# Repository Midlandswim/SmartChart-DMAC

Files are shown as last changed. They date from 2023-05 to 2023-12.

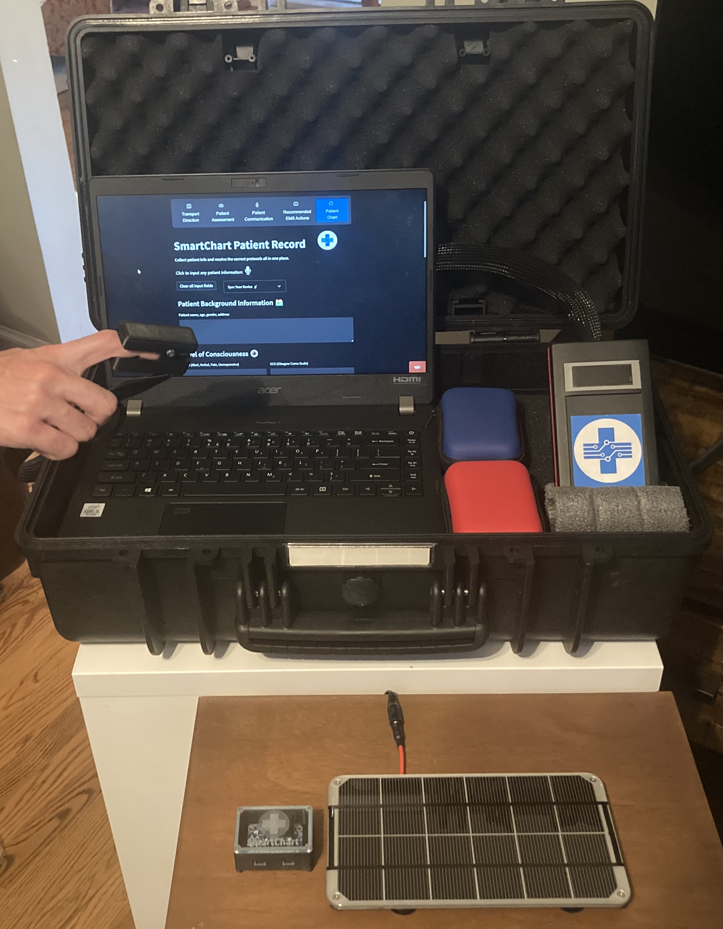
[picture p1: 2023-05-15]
Visuals/Photos/IMG_8333.jpg

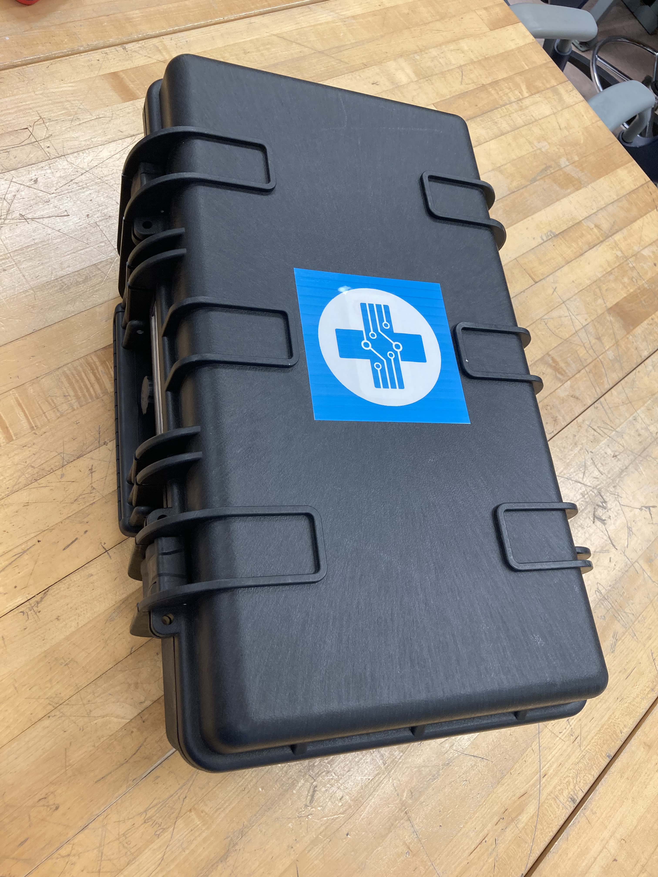
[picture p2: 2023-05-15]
Visuals/Photos/IMG_8315 (1).jpg

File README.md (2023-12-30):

# SmartChart & DMAC Research
SmartChart Patient Charting App and the Deployable Medical Assistance Case

Researcher: Wilson Dhalwani & Giacomo Pugliese <br />
Advisors: Mr. Michael Liva (BCA) & Mr. Joseph Barbetta (BCA) & Mr. Oliver Dobrich (BCA) & Ms. Clare Kennedy (BCA) <br />
Context: Future Health Professionals (HOSA) International Leadership Conference Medical Innovation <br />
Project Name: SmartChart & Deployable Medical Assistance Case <br />
Start Date: April 04, 2023 <br />

The following repository is for documenting and sharing my work in this research competition and its related fields of engineering and medicine. This was also made for recording my process of solving the issue at hand so that others can learn and build upon my work. An award-winning software that is the most intelligent and efficient virtual patient charting application for emergency medical technicians on the market, SmartChart utilizes an algorithm that suggests treatment based on patient information. A machine learning model provides diagnostics and appropriate protocols, and more. SmartChart supports audio transcription and translation for patient charting and communication, as well as OCR for written notes. The DMAC was made for our entry into the Medical Innovations Category at HOSA ILC. The team previously won 1st place at the HOSA New Jersey State Conference for Medical Innovation, allowing us to qualify for HOSA ILC in Dallas, TX, in 2023. I was not officially a member of the team during this time, only joining after their accomplishment at the New Jersey State Conference due to scheduling conflicts keeping me from joining the team in an official capacity prior to ILC Qualification. This is why I acted as an unofficial engineering consultant for the project up until the end of the New Jersey State Conference. We finished as semifinalists at HOSA ILC 2023, placing in the top 40 teams in the World. This was done in a team consisting of Giacomo Pugliese, Andrea Kim, and myself. I was the engineer in the group and personally designed the entire DMAC environment, including the aesthetics, custom enclosures, device programming, and solar power systems. The goal of this project is to work in concert with SmartChart, using AI to process and collect data to diagnose and treat patients. Used by EMTs, the DMAC and SmartChart will help revolutionize emergency patient care. This project is also patent pending, with the team recently being granted a provisional utility patent for the entire system. This project has no end date as an innovation never ends, rather, continues until the idea is forgotten, and my hope is that this work can be the basis for future engineers who, too, find great excitement in innovation and design. Featured by multiple news outlets. 
Here is the link to one by Yahoo Finance: https://finance.yahoo.com/video/students-design-smartchart-app-help-195534932.html?guccounter=1 <br />

<p align="center"> <strong> Promotional Video: </strong> </p> 

https://github.com/Midlandswim/SmartChart-DMAC/assets/87616332/fc35b12c-a720-4e8d-b312-f2718276814c

<br />

Should you have any questions, comments, or just wish to reach out, email me at wilson.dhalwani@gmail.com !

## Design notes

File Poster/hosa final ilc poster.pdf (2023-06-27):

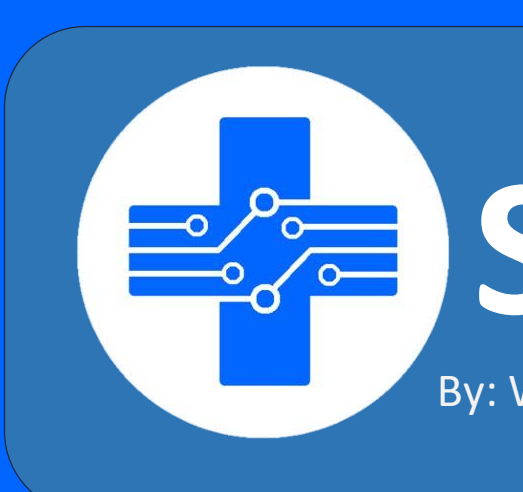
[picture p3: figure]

### By: Wilson Dhalwani, Andrea Kim, & Giacomo Pugliese

### MISSION STATEMENT

EMT workers are often put under high pressure, where providing the right diagnosis and treatment can mean life or death for the patient. Our mission is to create an app and hard case with integrated artificial intelligence and computer vision for EMTs, that enhances their ability to provide timely and effective care to patients. With this, we seek to minimize the time EMTs spend on documentation or looking up protocols, allowing them to maximize their time spent on patient care and call planning. We believe that our app has the potential to revolutionize the way EMTs deliver emergency medical care, enabling them to make more informed decisions and provide faster, more effective treatment to patients.

### OUR INNOVATION

We created an artificial intelligence integrated web application, SmartChart, designed for the efficient and consistent delivery of EMS care. An interface was created for EMTs to record vitals and patient care summaries while continuously updating the patient care suggestions tab, a separate page that includes a patient care overview recommended by the algorithm. In addition, a machine learning model was created to take in images and return possible patient complications. Other features included are on-demand translations for language barriers and transport directions to recommended medical facilities. This app is paired with our DMAC, or Deployable Medical Assistance Case. This is an entire environment for recording and storing data, taken by inbuilt sensors or human interface. It is capable of taking real time vitals and sending them to SmartChart, for AI related processing.

### Recommended EMS Actions

- Lists recommended actions that live updates dynamically to each patient, according to the algorithm.
- Each result also indicates possible contraindications and relative contraindications based on the patient’s information.

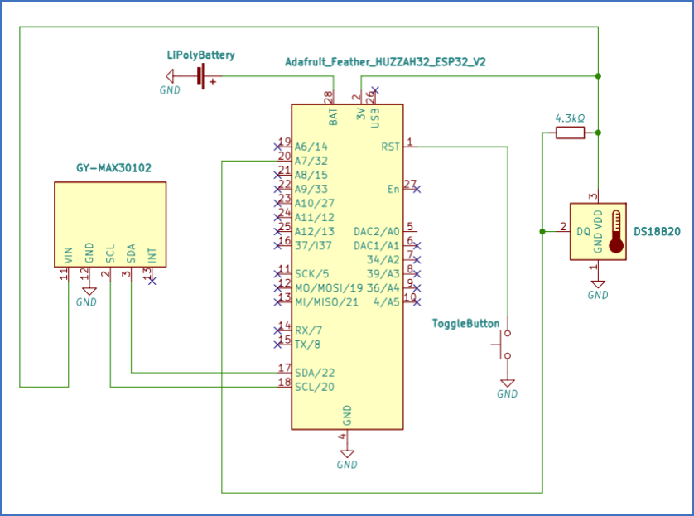
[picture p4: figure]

### Transport Directions

- Alerts EMT about inclement weather conditions.
- Provides a list of the nearest facilities including hospitals, burn centers, trauma centers, stroke centers, and cardiac centers.
- Recommends and reorders nearby facility types and provides directions based on patient information.

### Patient Communication

- On-demand translations help with language barriers
- Conversations can be audio or text-based
- 10 language options to translate the EMT or the patient’s message

### HOW IT WORKS

In the web app, users can navigate through the different tabs by using a convenient navigation bar.

### Patient Chart

- EMTs can enter vitals manually or use the voice input to save time. There is also an area for inputting the EMTs hand written care report into the chart using optical character recognition
- AI was designed for the voice input understand recognize all speech patterns, understand them in any order, and take as many vitals as needed.
- Patient charts can be saved and exported.

### PRACTITIONERS & TRAINING REQUIREMENTS

This app and case are created for EMTs to use on-duty. Users must be certified EMTs in order to ensure that they have the background knowledge and training necessary, to correctly carry-out actions. The case and website are easy to use and maintain.

### COST ANALYSIS

Combined, the total material cost of SmartChart per case comes to be less than $150 (excluding the computer). The web app has no costs other than maintenance activities and hosting. Our goal is to provide quality healthcare to all people, so we want to minimize the price as much as possible. To do this, SmartChart could apply for an SBIR grant (small business innovation research). Funding would be used to find ways to minimize costs of production and further develop the product.

### IMPACT ON FUTURE HEALTHCARE

Our goal is to empower EMTs with the tools and knowledge they need to save lives, reduce patient morbidity and mortality, and improve the overall quality of emergency medical care. We hope that by using our app, patients can receive faster and more accurate diagnoses as well as receive the quality treatment they need.

# SmartChart

The algorithm for determining all possible patient conditions according to their information chart:

**Disclaimer: All above images are original student images**

3D render of custom CAD finger pulse oximeter clip:

The electronic schematic for the deployable medical assistance case enclosure:

3D render of custom CAD solar charger enclosure:

### THE DEPLOYABLE MEDICAL ASSISTANCE CASE (DMAC)

The DMAC houses a microcontroller, a pulse oximeter, a temperature probe, and a secure and portable electronics enclosure for the battery. The enclosure includes a customizable LiPo battery system and onboard Wi-Fi interfacing. The DMAC also comes with a solar panel system capable of fully charging the case in just about 60 minutes. The data is then sent, recorded, and processed in real-time, allowing for accurate and efficient care of the patient.

### Adafruit ESP32 Feather HUZZAH V2

A compact and powerful microcontroller board based on the ESP32 chipset. It offers built-in Wi-Fi and Bluetooth capabilities, making it ideal for projects requiring wireless connectivity. With its small form factor and rich features, it enables easy prototyping and development of IoT applications.

### Adafruit MCP73871 Solar Charger

A handy device designed to charge Lithium Polymer (LiPo) batteries using solar power. It incorporates a specialized charging chip that efficiently regulates charging, ensuring optimal battery performance and longevity. It is an excellent choice for projects that require sustainable and eco-friendly power sources.

### GY-MAX30102 Pulse Ox and Heart Rate Sensor

A highly sensitive and accurate sensor module that measures both heart rate and blood oxygen saturation levels. It utilizes infrared and red-light sensors to detect changes in blood volume, providing valuable data for monitoring health and wellness.

### DS18B20 Temperature Sensor

A digital thermometer that measures temperature with high precision. It uses a unique one-wire protocol, allowing multiple sensors to be connected to a single microcontroller pin. It has a compact size and waterproof casing.

### Adafruit LiPo Battery 3.7V 500mAh

A rechargeable Lithium Polymer (LiPo) battery specifically designed for small electronic projects. It offers a high energy density and a compact form factor, making it suitable for applications where space is limited.

Source: Adafruit Industries

Source: Adafruit Learning Systems

Source: Amazon

Source: Adafruit Industries

### Patient Assessment

- Trained a machine learning model to classify different patient presentations using computer vision technology.
- Presents relevant protocols based on classification to save time for the EMT

Source: Amazon

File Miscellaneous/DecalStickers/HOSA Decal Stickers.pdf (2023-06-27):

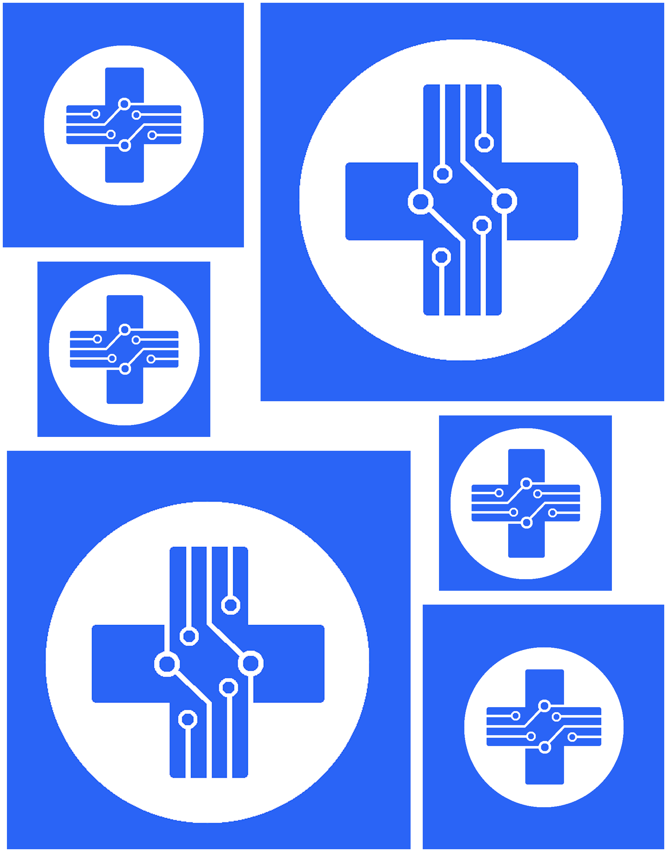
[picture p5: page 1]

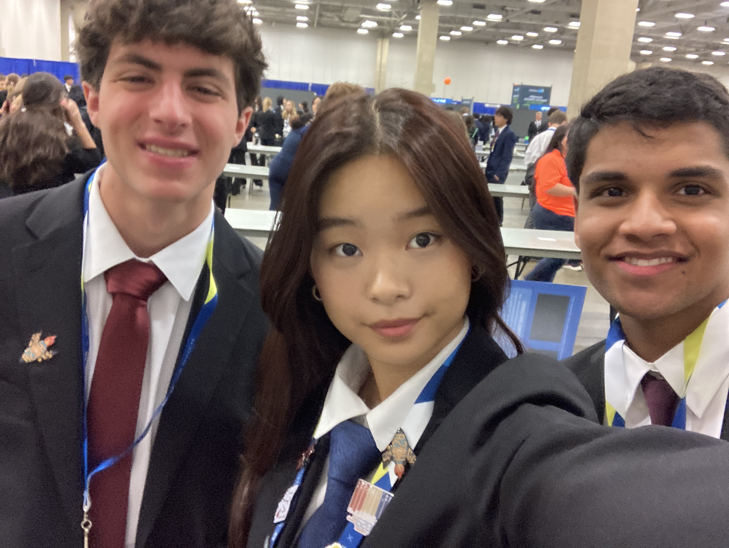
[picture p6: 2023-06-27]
Visuals/Photos/HOSAGroupPhotoPic.jpg

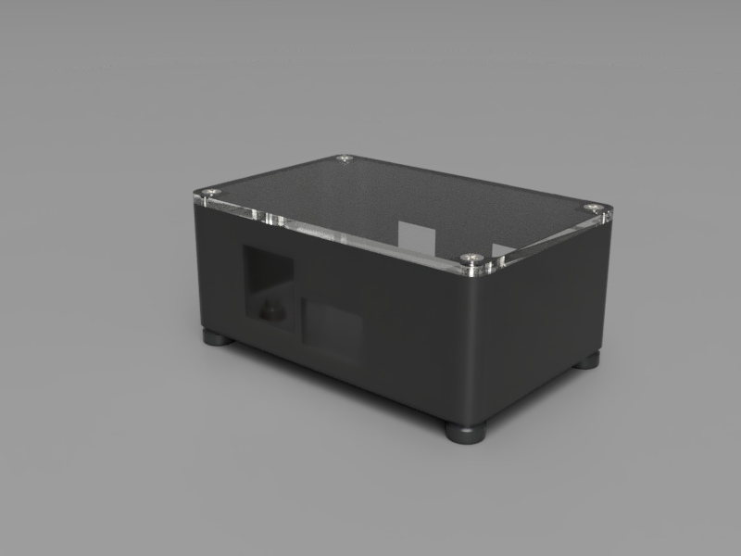
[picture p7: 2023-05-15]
Visuals/Renders/MCP73871Enclosure_2023-May-13_01-03-16AM-000_CustomizedView6770993901_png.png

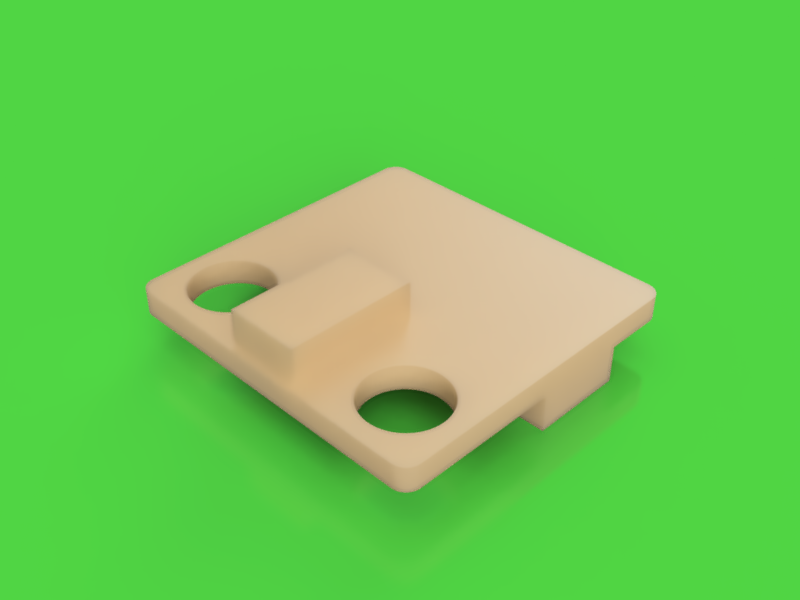
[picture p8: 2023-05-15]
Visuals/Renders/GY-MAX30102PCBRender1.png

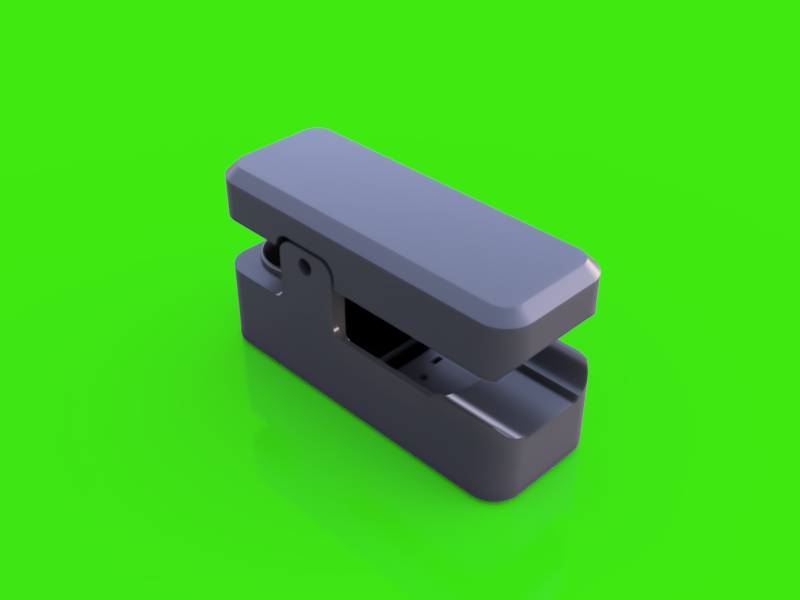
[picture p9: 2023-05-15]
Visuals/Renders/PulseOxiRender6.png

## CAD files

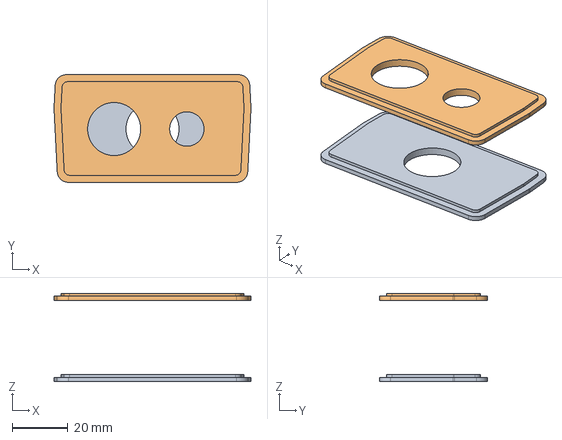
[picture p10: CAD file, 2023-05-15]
CAD/Components/Enclosure Walls/HOSAEnclosureWalls STEP.step
70.4 x 38.5 x 31.5 mm

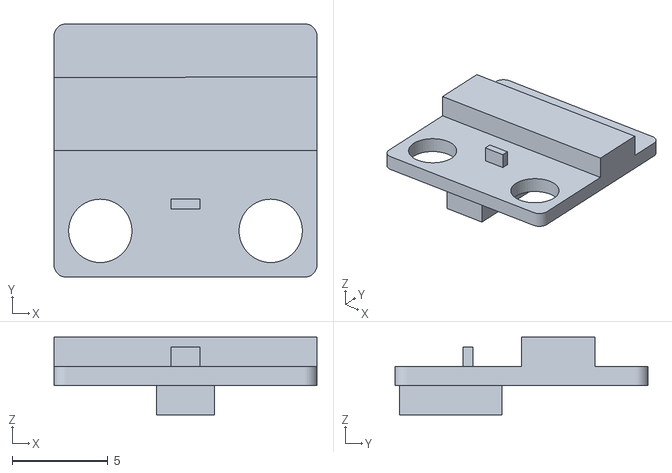
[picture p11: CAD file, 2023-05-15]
CAD/Components/GY-MAX30102/GY-MAX30102 Component STL.stl
13.7 x 13.2 x 4.06

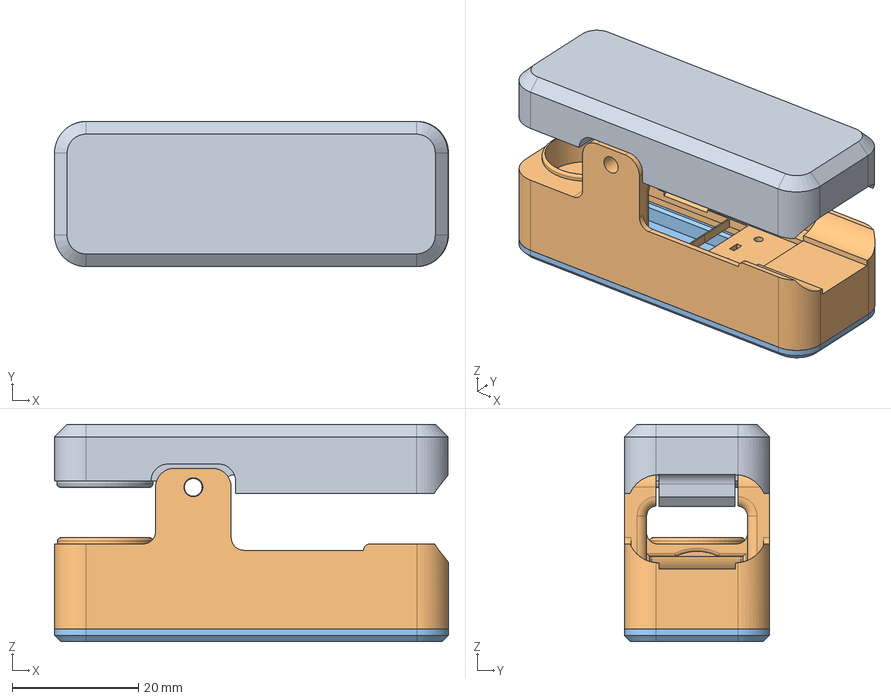
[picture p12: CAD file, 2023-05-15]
CAD/Pulse Oximeter Clip/PulseOximeterClip STEP.step
62.5 x 23.0 x 34.5 mm
Top
Bottom

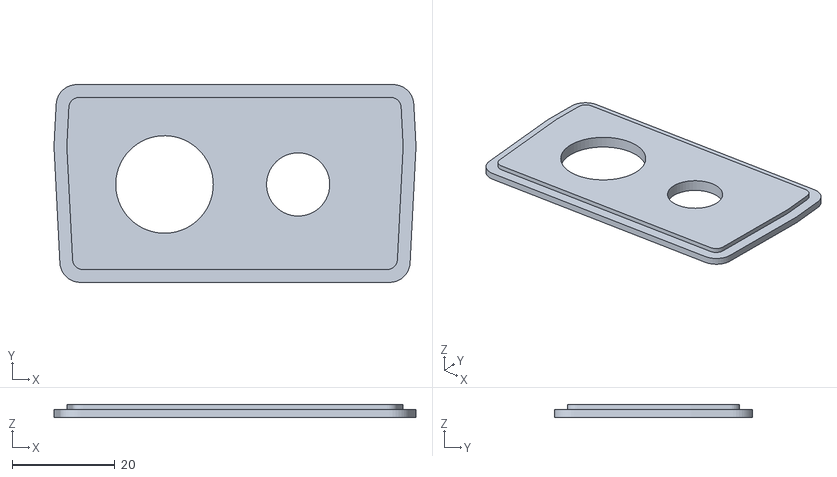
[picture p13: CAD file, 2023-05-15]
CAD/Components/Enclosure Walls/HOSAEnclosureWalls DoubleHole STL.stl
70.4 x 38.5 x 2.50

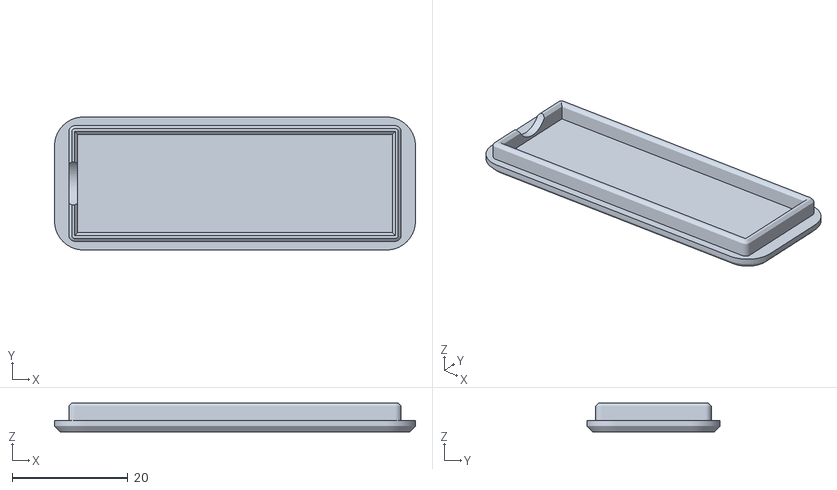
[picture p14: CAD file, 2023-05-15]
CAD/Pulse Oximeter Clip/PulseOximeterClip Bottom STL.stl
62.4 x 23.0 x 5.00

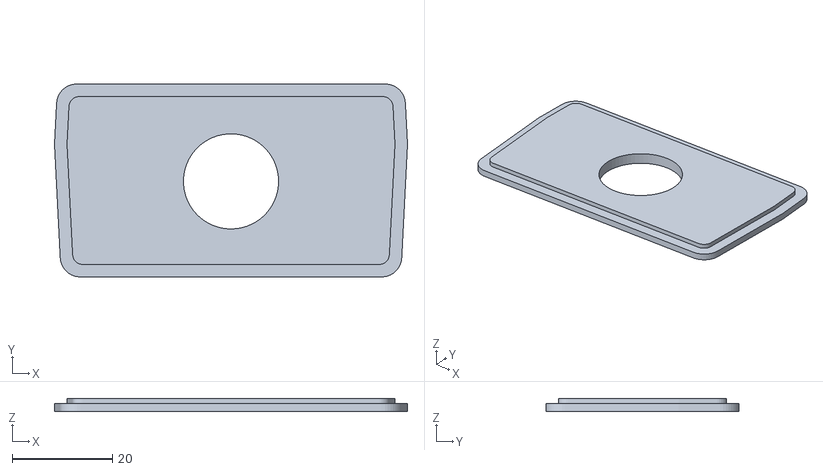
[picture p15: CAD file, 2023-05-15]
CAD/Components/Enclosure Walls/HOSAEnclosureWalls SingleHole STL.stl
70.4 x 38.5 x 2.50

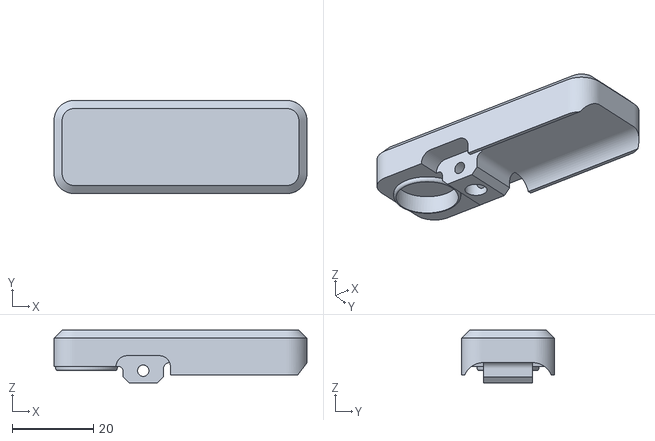
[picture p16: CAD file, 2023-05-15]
CAD/Pulse Oximeter Clip/PulseOximeterClipTop STL.stl
62.4 x 23.0 x 13.0

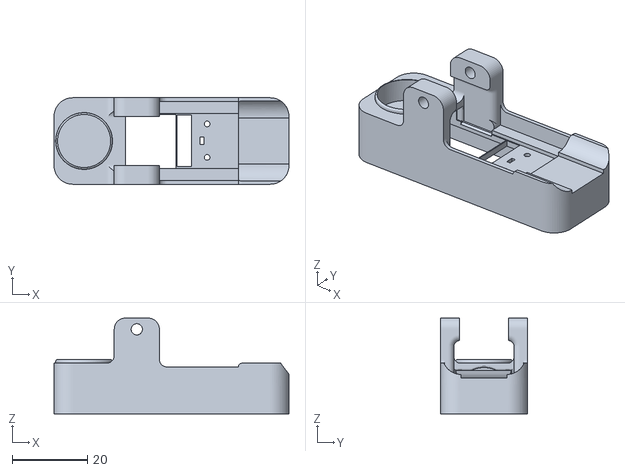
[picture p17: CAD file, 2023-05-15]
CAD/Pulse Oximeter Clip/PulseOximeterClipMiddle STL.stl
62.4 x 23.0 x 25.5

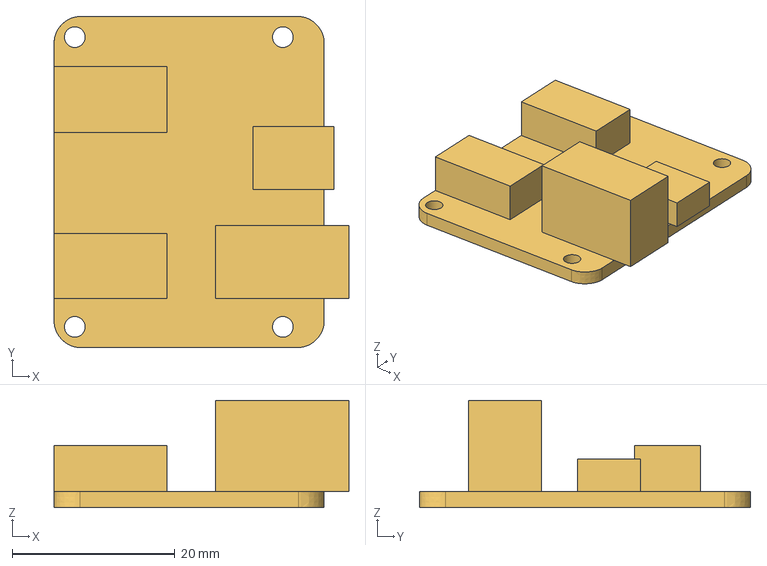
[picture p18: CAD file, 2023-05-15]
CAD/Components/MCP73871/MCP73871 Solar Charger Controller STEP.step
36.2 x 40.7 x 13.2 mm

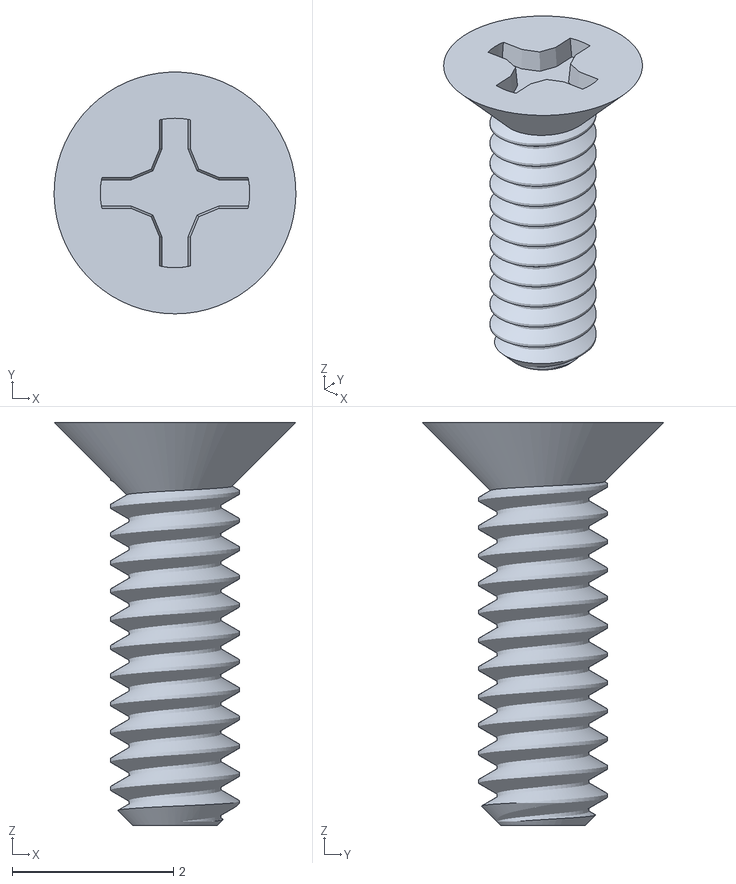
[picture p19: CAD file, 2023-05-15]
CAD/Components/Screws/92010A781_Passivated 18-8 Stainless Steel Phillips Flat Head Screw STL.stl
3.00 x 3.00 x 5.00

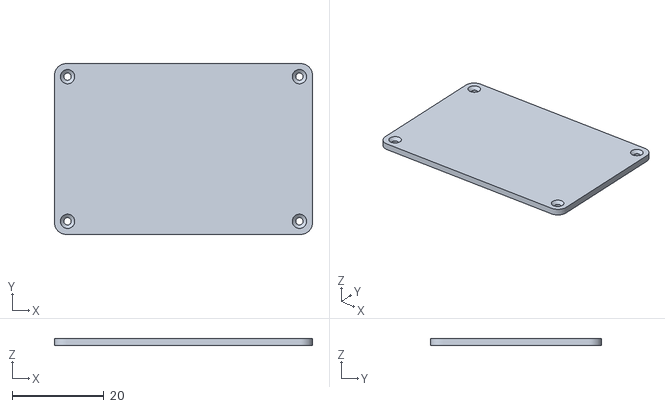
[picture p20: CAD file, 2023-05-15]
CAD/Solar Charger Enclosure/MCP73871Enclosure Accrylic Cover STL.stl
56.3 x 37.2 x 1.59

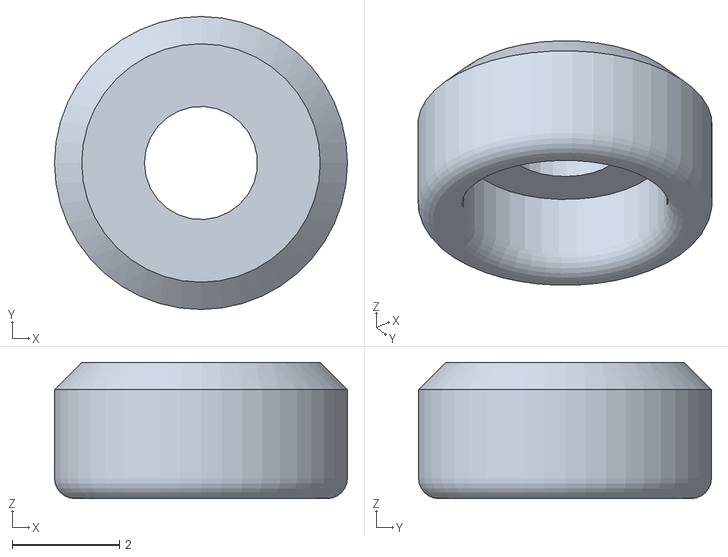
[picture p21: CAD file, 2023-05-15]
CAD/Solar Charger Enclosure/MCP73871Enclosure Leg STL.stl
5.46 x 5.46 x 2.54

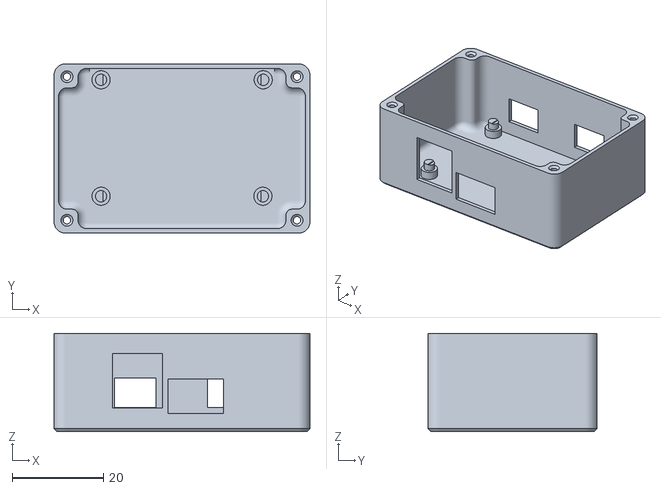
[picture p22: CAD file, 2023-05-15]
CAD/Solar Charger Enclosure/MCP73871Enclosure Body STL.stl
56.3 x 37.2 x 21.6

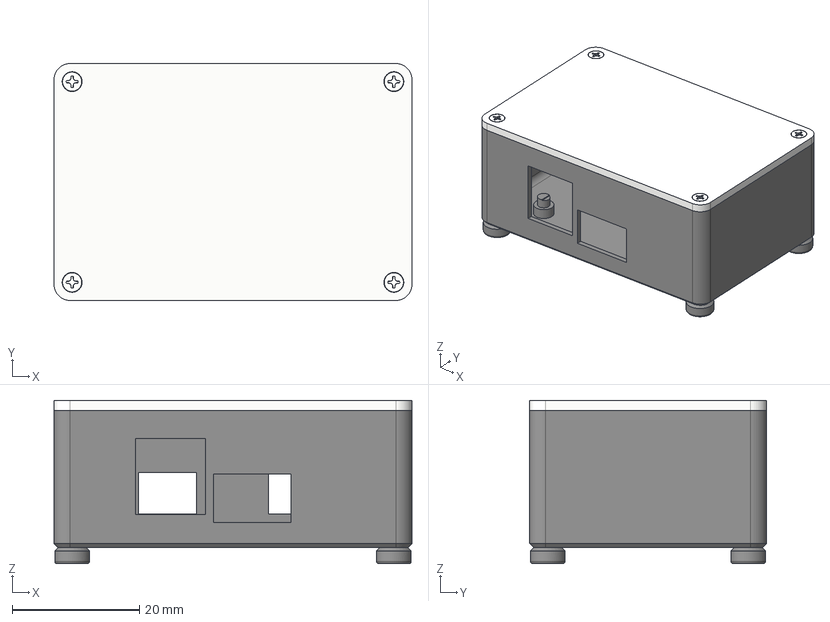
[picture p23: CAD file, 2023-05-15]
CAD/Solar Charger Enclosure/MCP73871Enclosure STEP.step
56.3 x 37.2 x 25.7 mm
92010A781_Passivated 18-8 Stainless Steel Phillips Flat Head Screw v2 x 8

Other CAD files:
CAD/Components/GY-MAX30102/GY-MAX30102 Component STEP.step
CAD/Components/Enclosure Walls/HOSAEnclosureWalls .step
CAD/Components/MCP73871/MCP73871 Solar Charger Controller STL.stl
CAD/Components/Screws/92010A781_Passivated 18-8 Stainless Steel Phillips Flat Head Screw STEP.step
CAD/Components/GY-MAX30102/GY-MAX30102 Component CAD.f3d
CAD/Components/MCP73871/MCP73871 Solar Charger Controller.f3d
CAD/Components/Screws/92010A781_Passivated 18-8 Stainless Steel Phillips Flat Head Screw .f3d
CAD/Pulse Oximeter Clip/PulseOximeterClip.f3z
CAD/Solar Charger Enclosure/MCP73871Enclosure .f3z

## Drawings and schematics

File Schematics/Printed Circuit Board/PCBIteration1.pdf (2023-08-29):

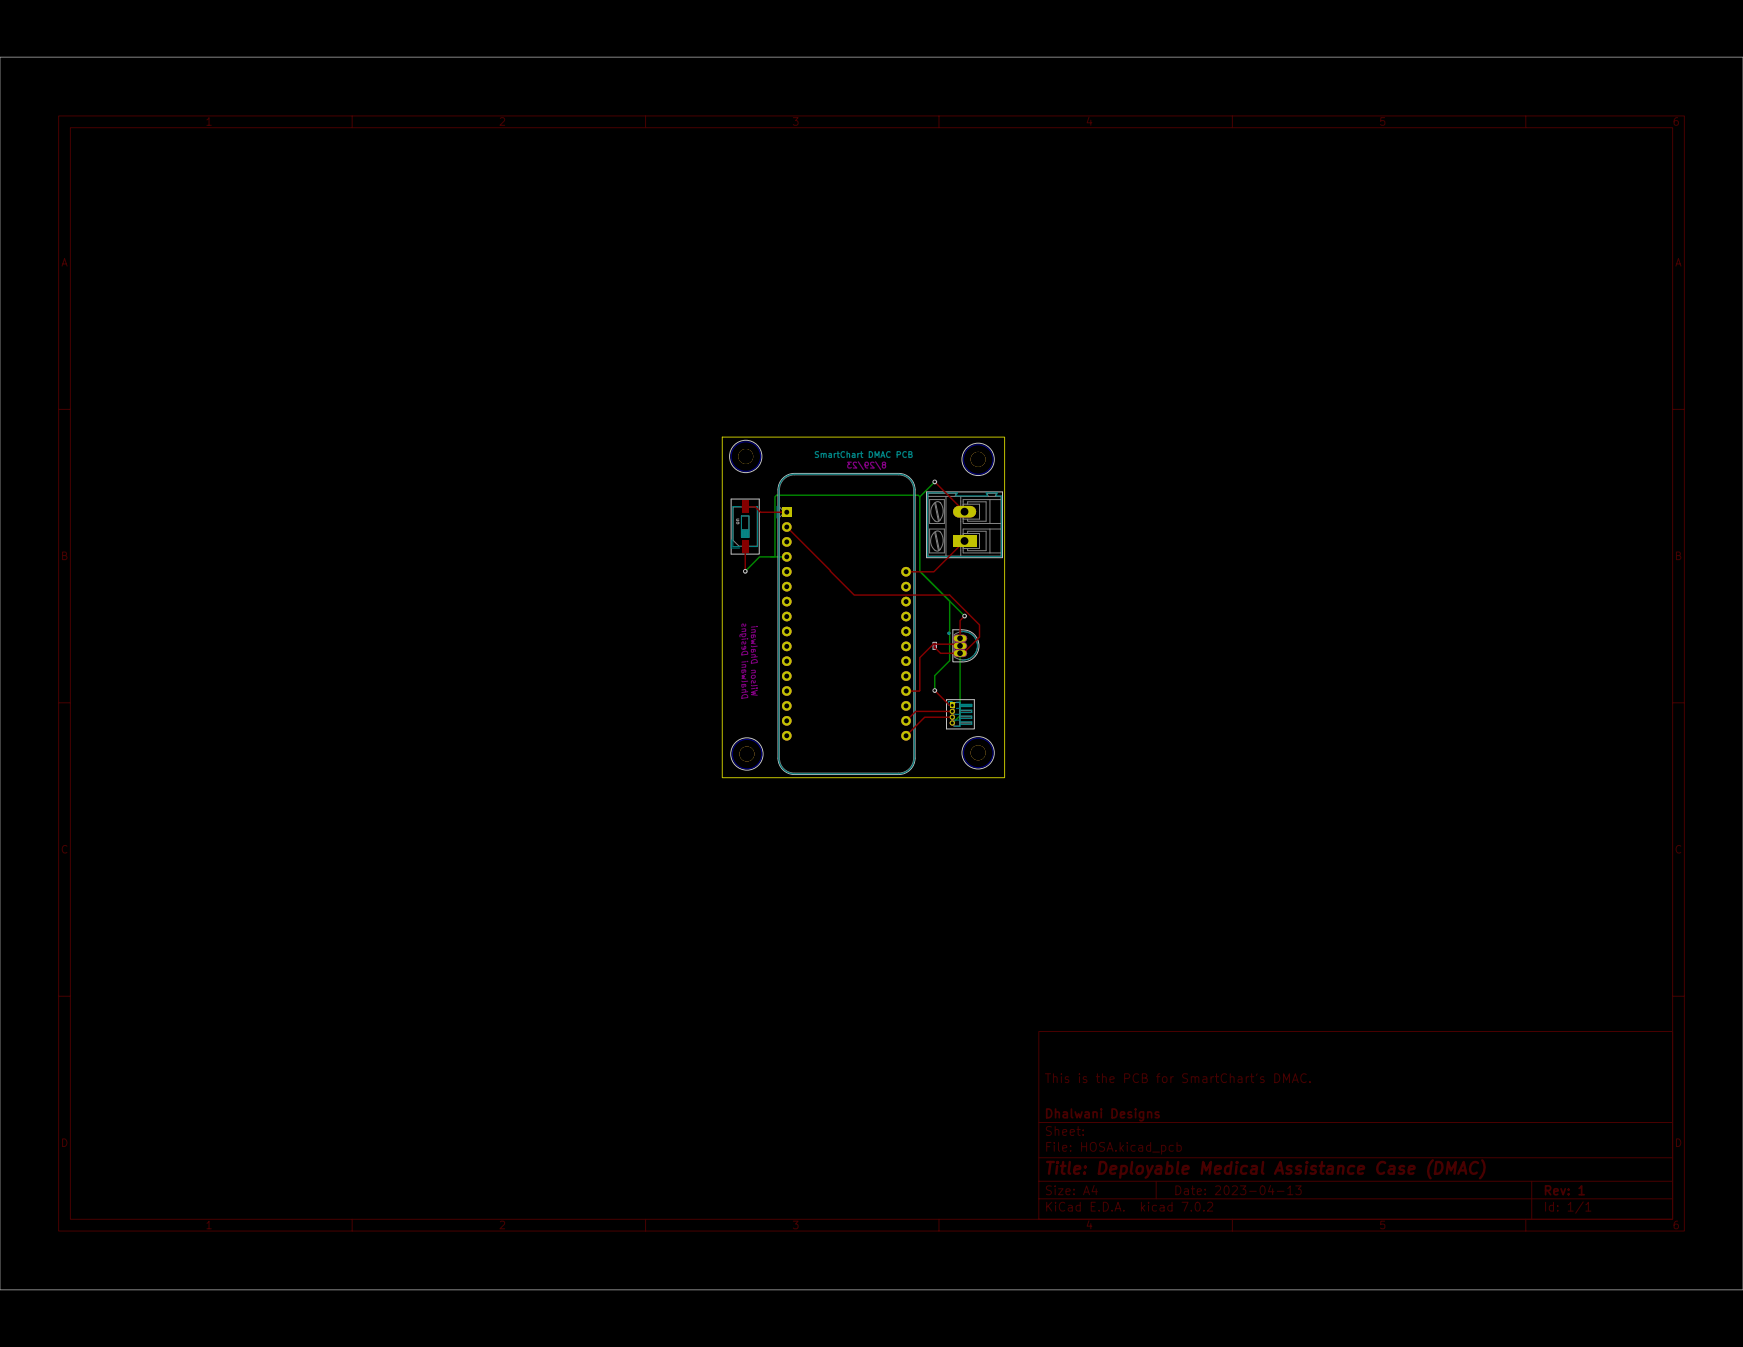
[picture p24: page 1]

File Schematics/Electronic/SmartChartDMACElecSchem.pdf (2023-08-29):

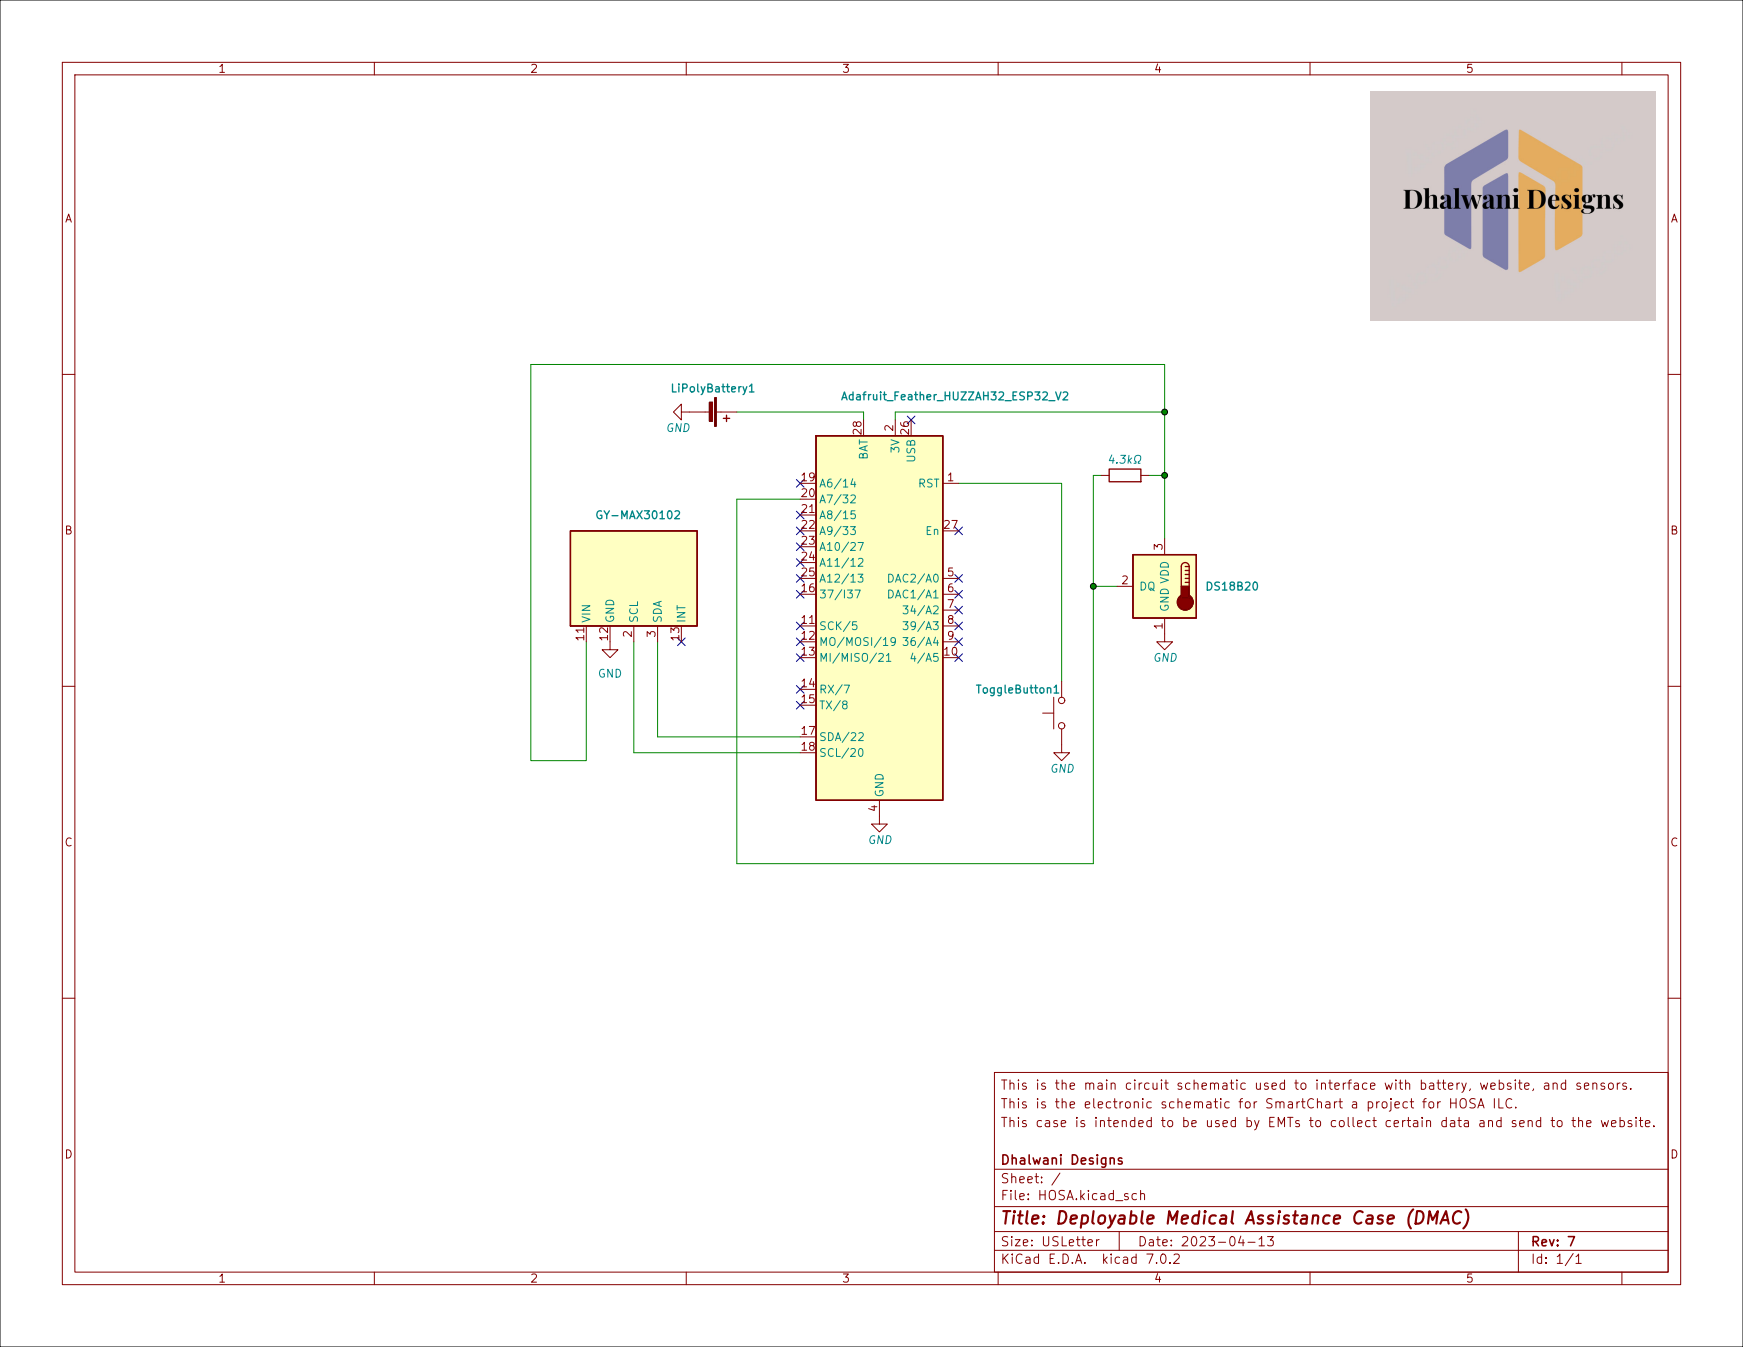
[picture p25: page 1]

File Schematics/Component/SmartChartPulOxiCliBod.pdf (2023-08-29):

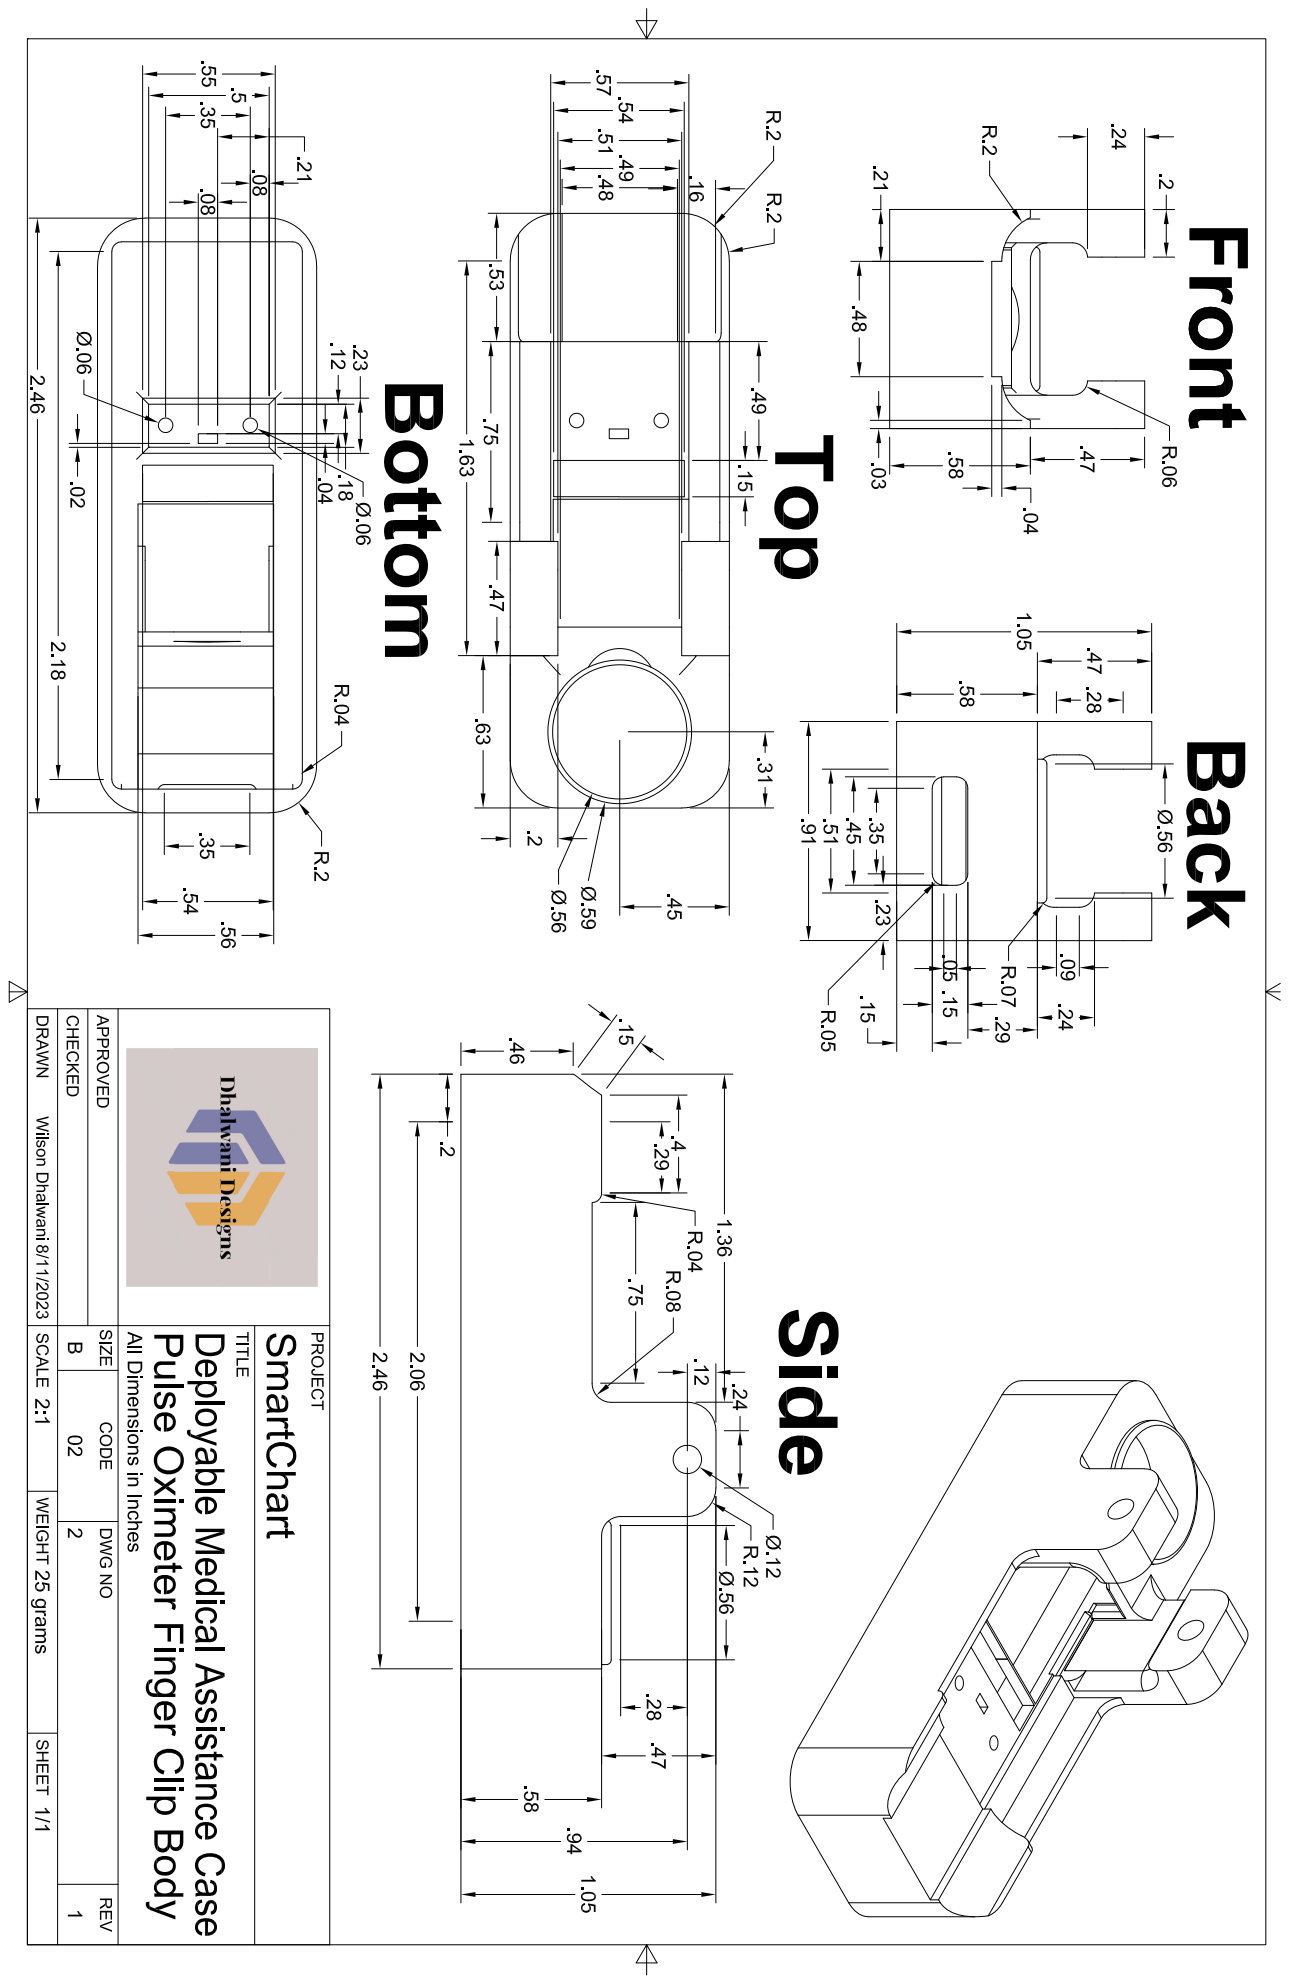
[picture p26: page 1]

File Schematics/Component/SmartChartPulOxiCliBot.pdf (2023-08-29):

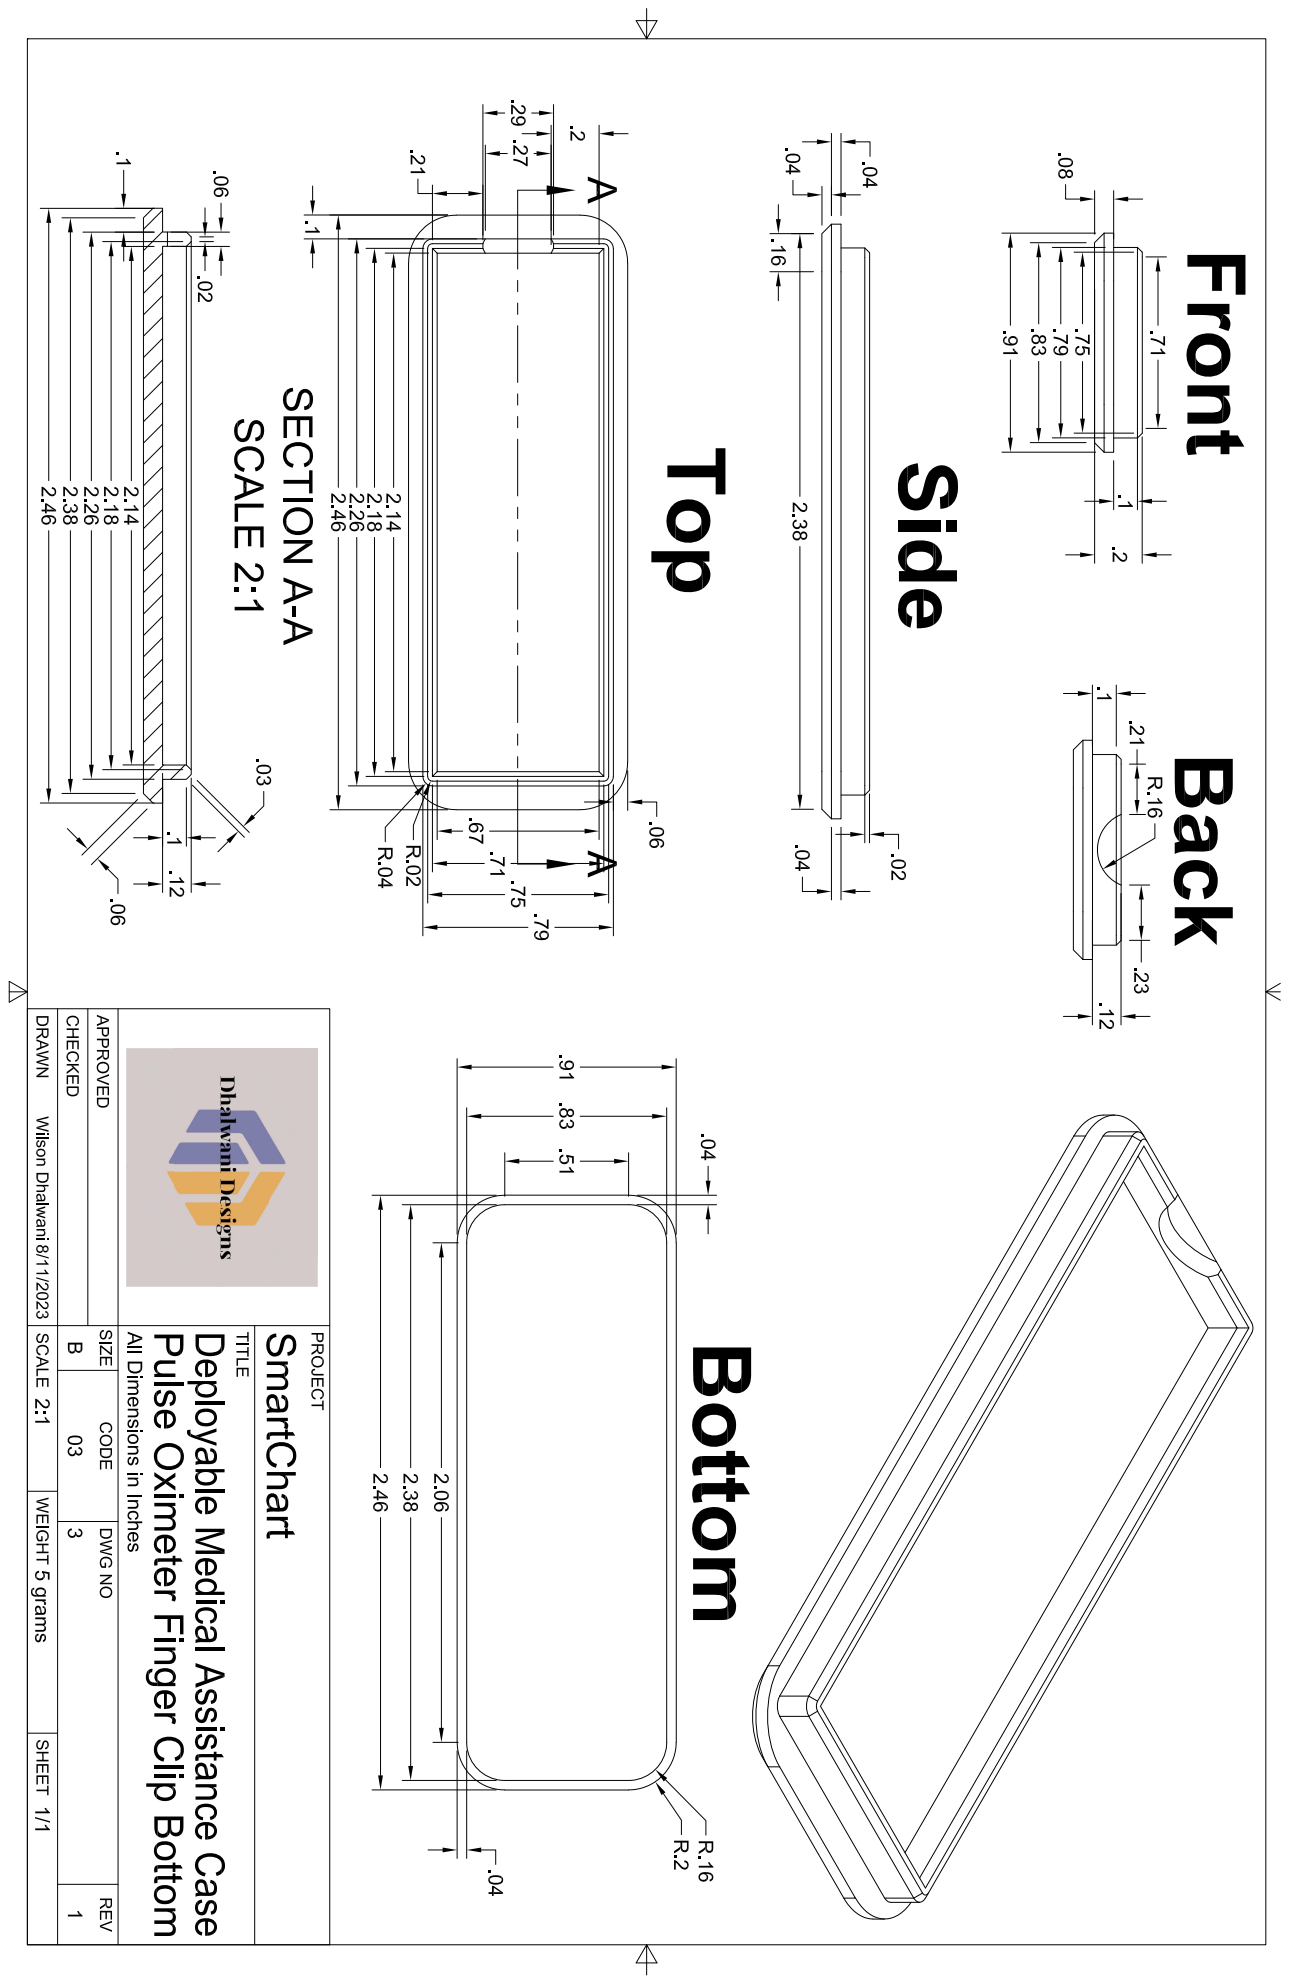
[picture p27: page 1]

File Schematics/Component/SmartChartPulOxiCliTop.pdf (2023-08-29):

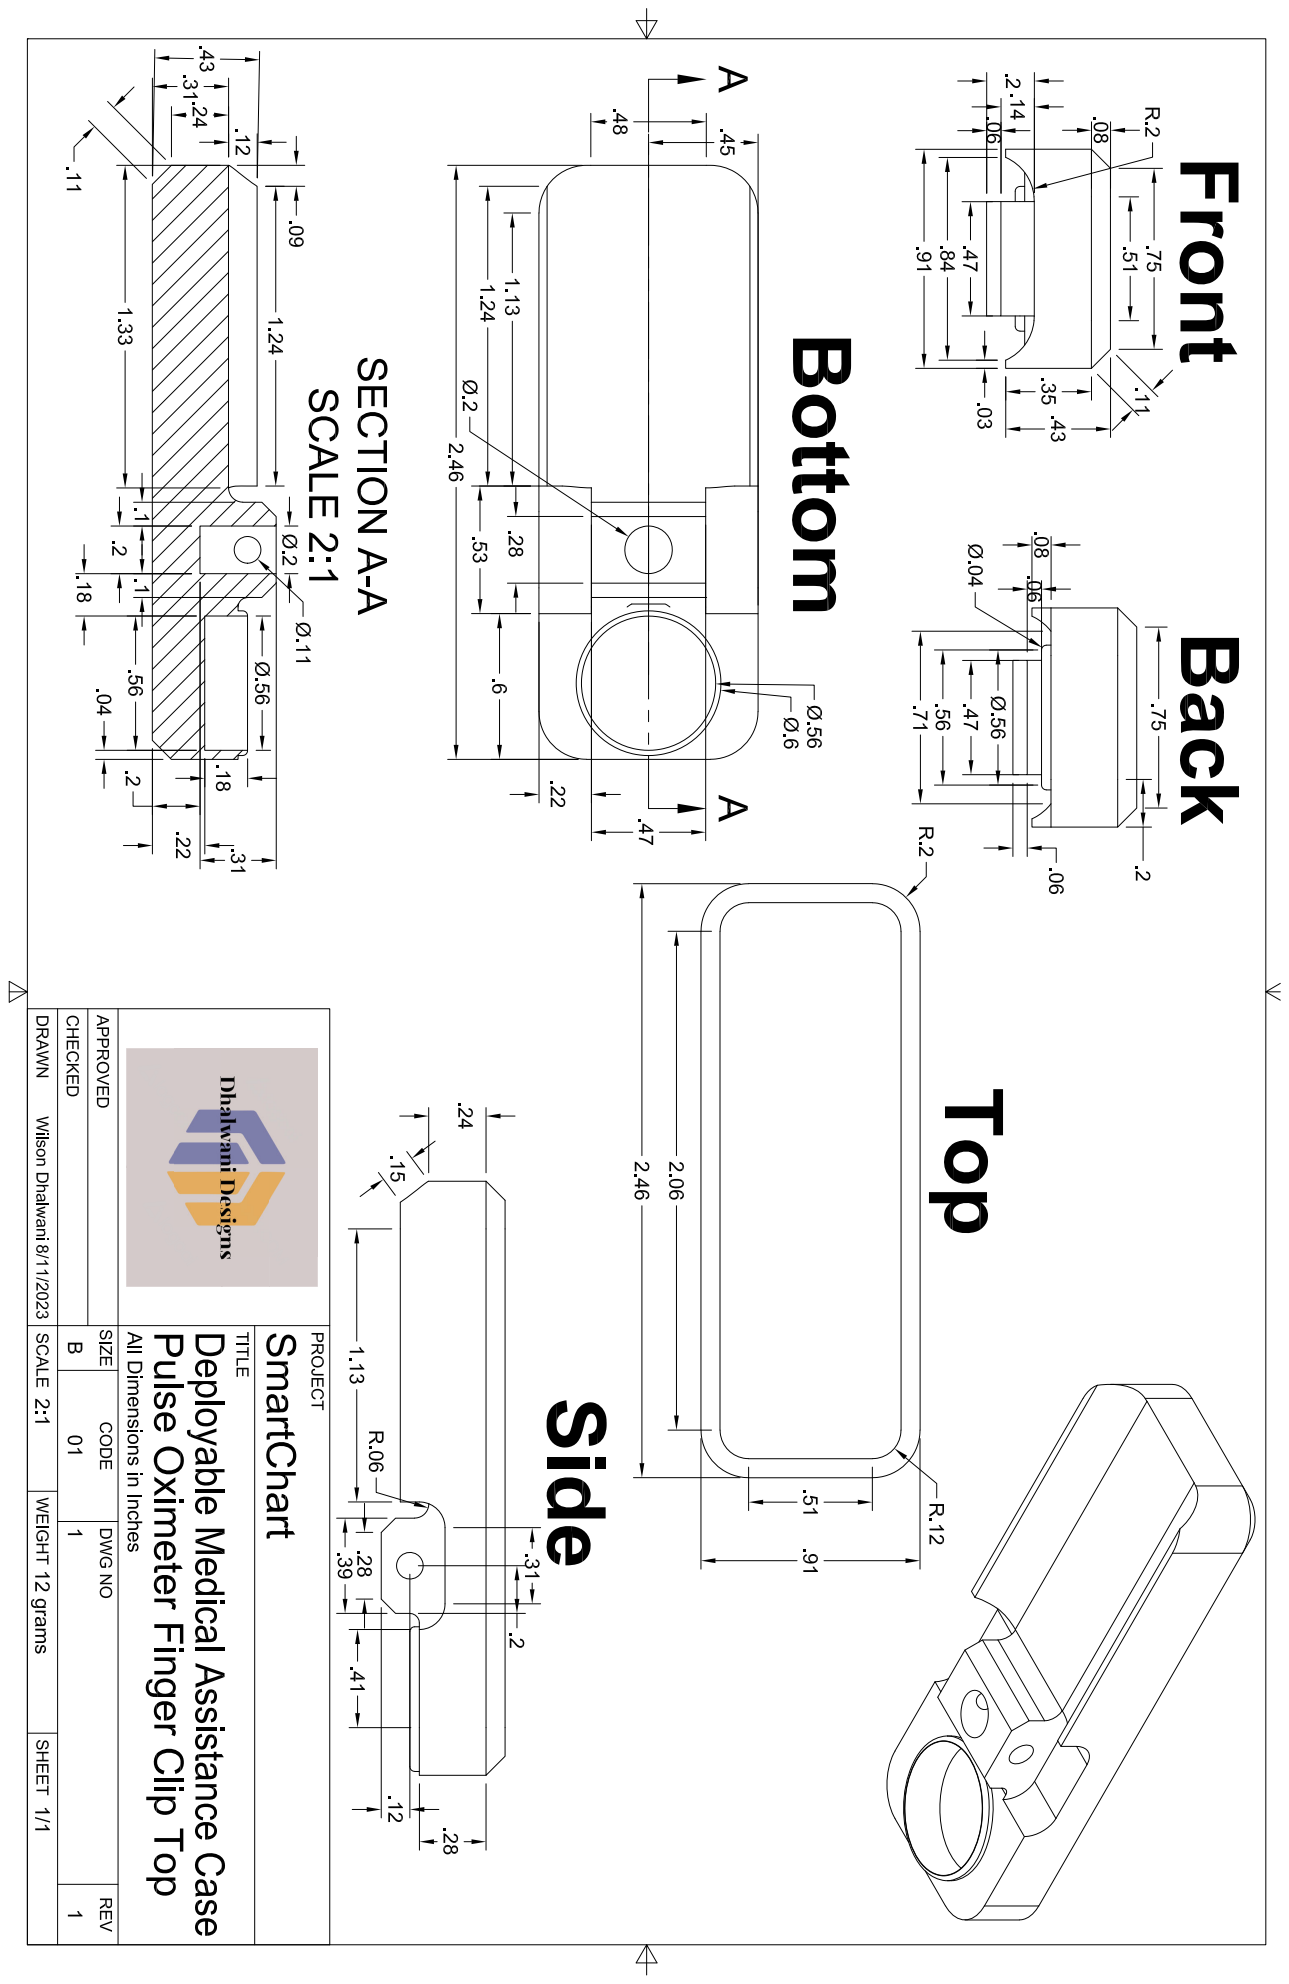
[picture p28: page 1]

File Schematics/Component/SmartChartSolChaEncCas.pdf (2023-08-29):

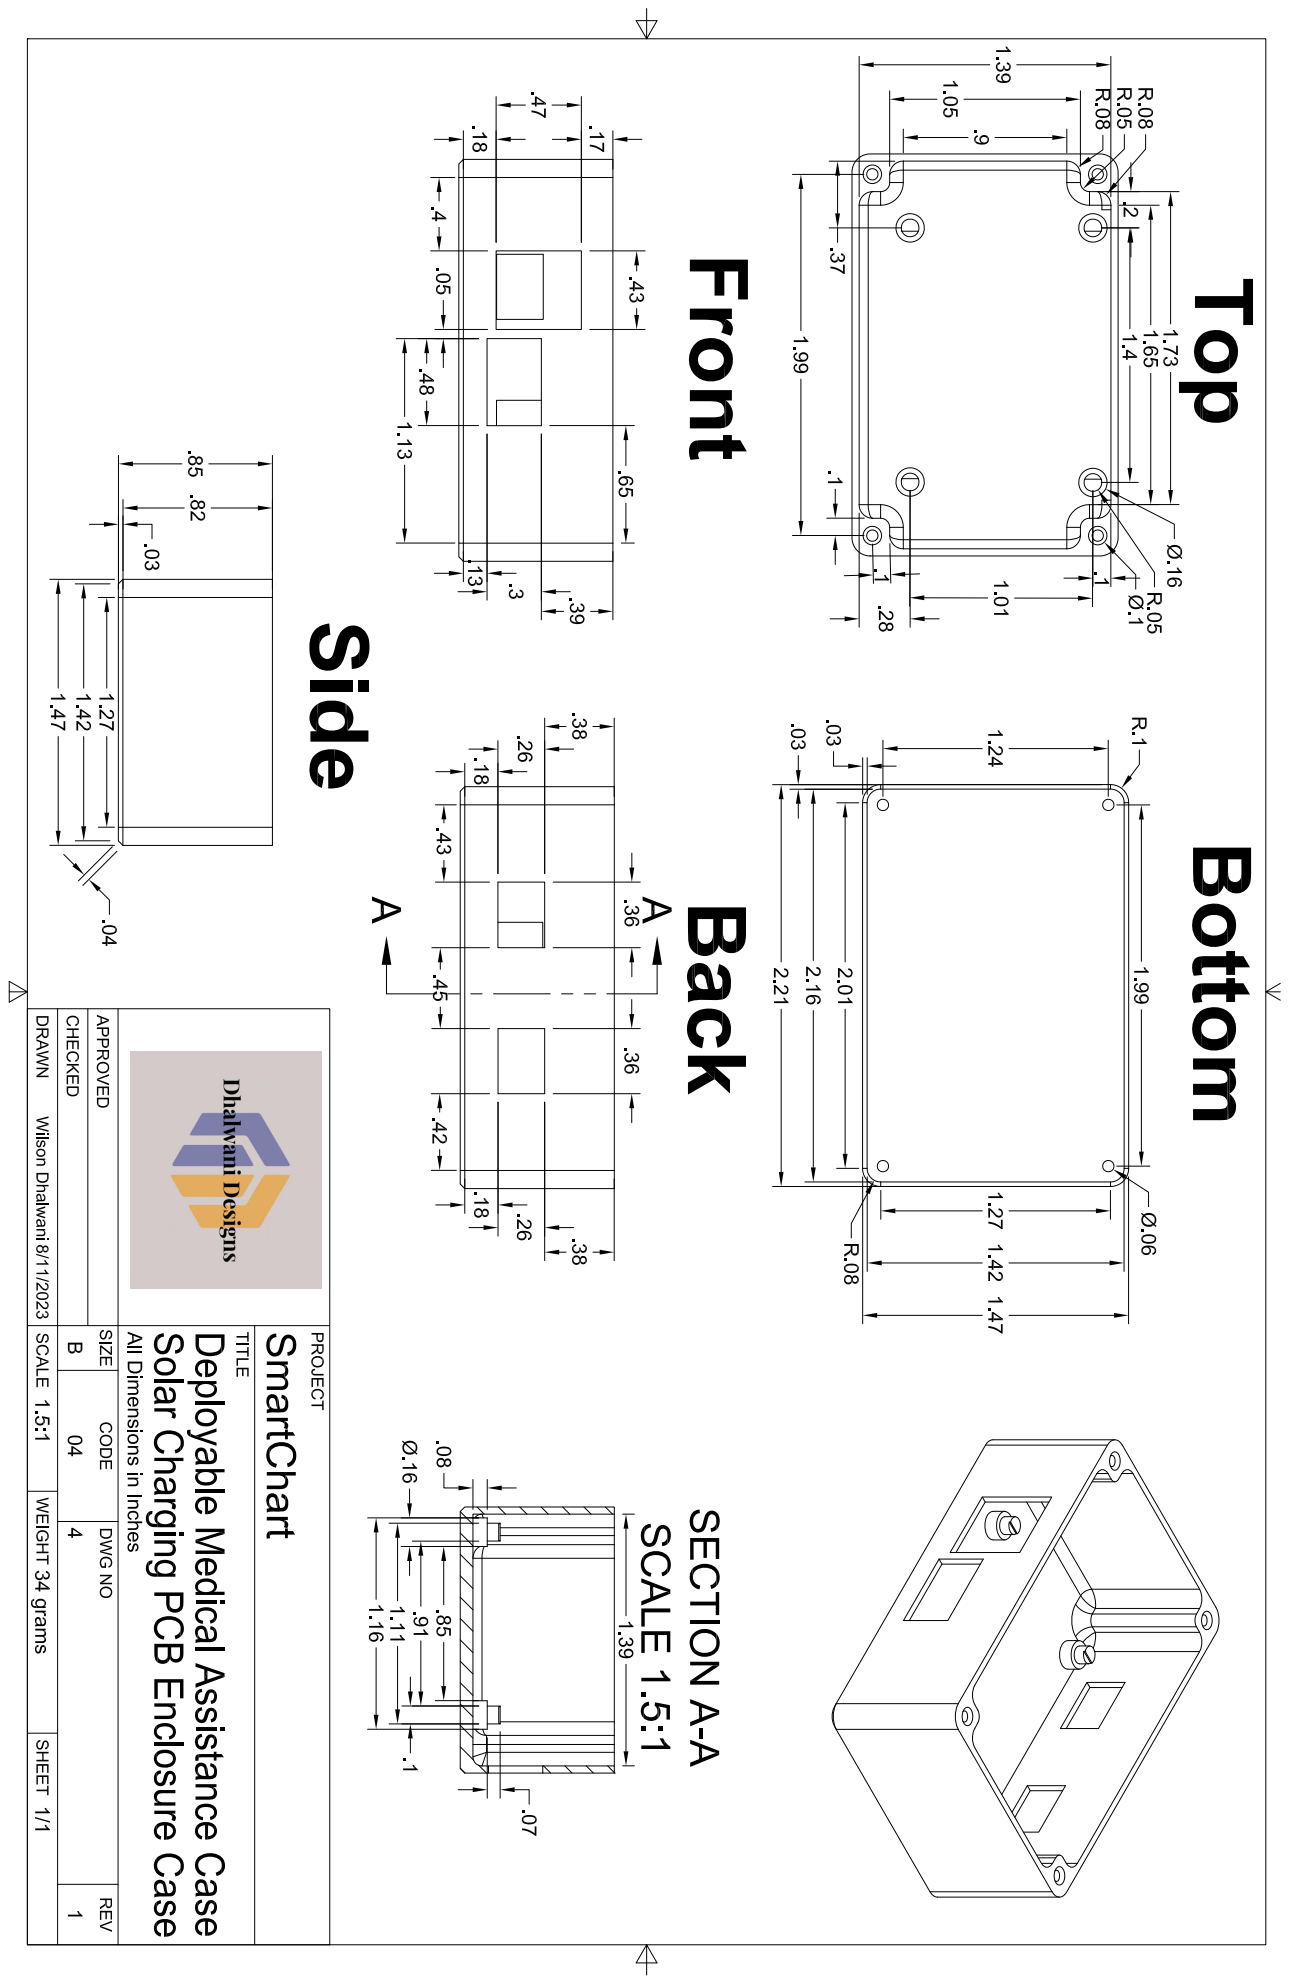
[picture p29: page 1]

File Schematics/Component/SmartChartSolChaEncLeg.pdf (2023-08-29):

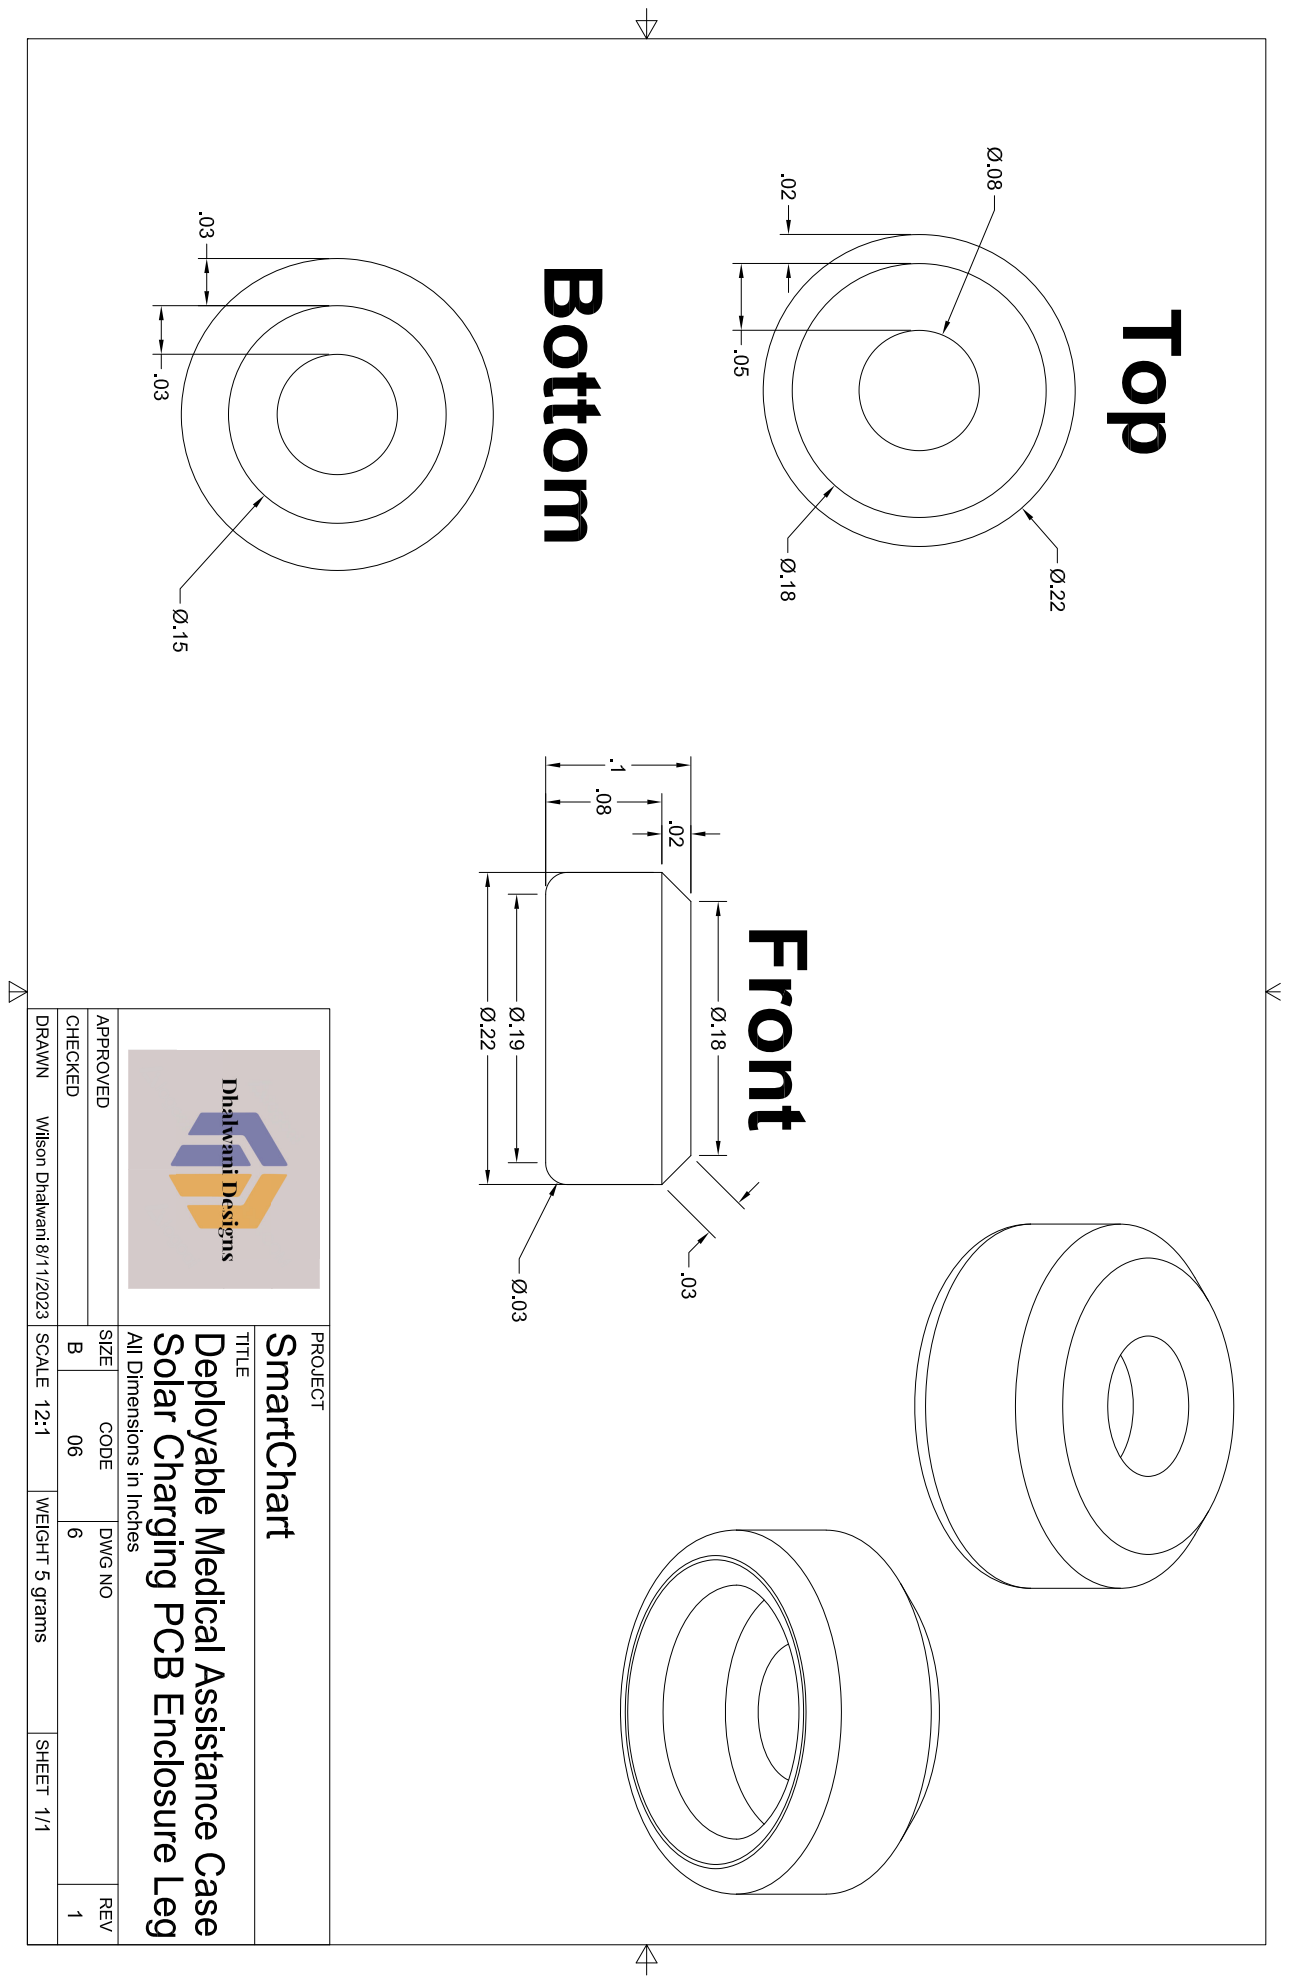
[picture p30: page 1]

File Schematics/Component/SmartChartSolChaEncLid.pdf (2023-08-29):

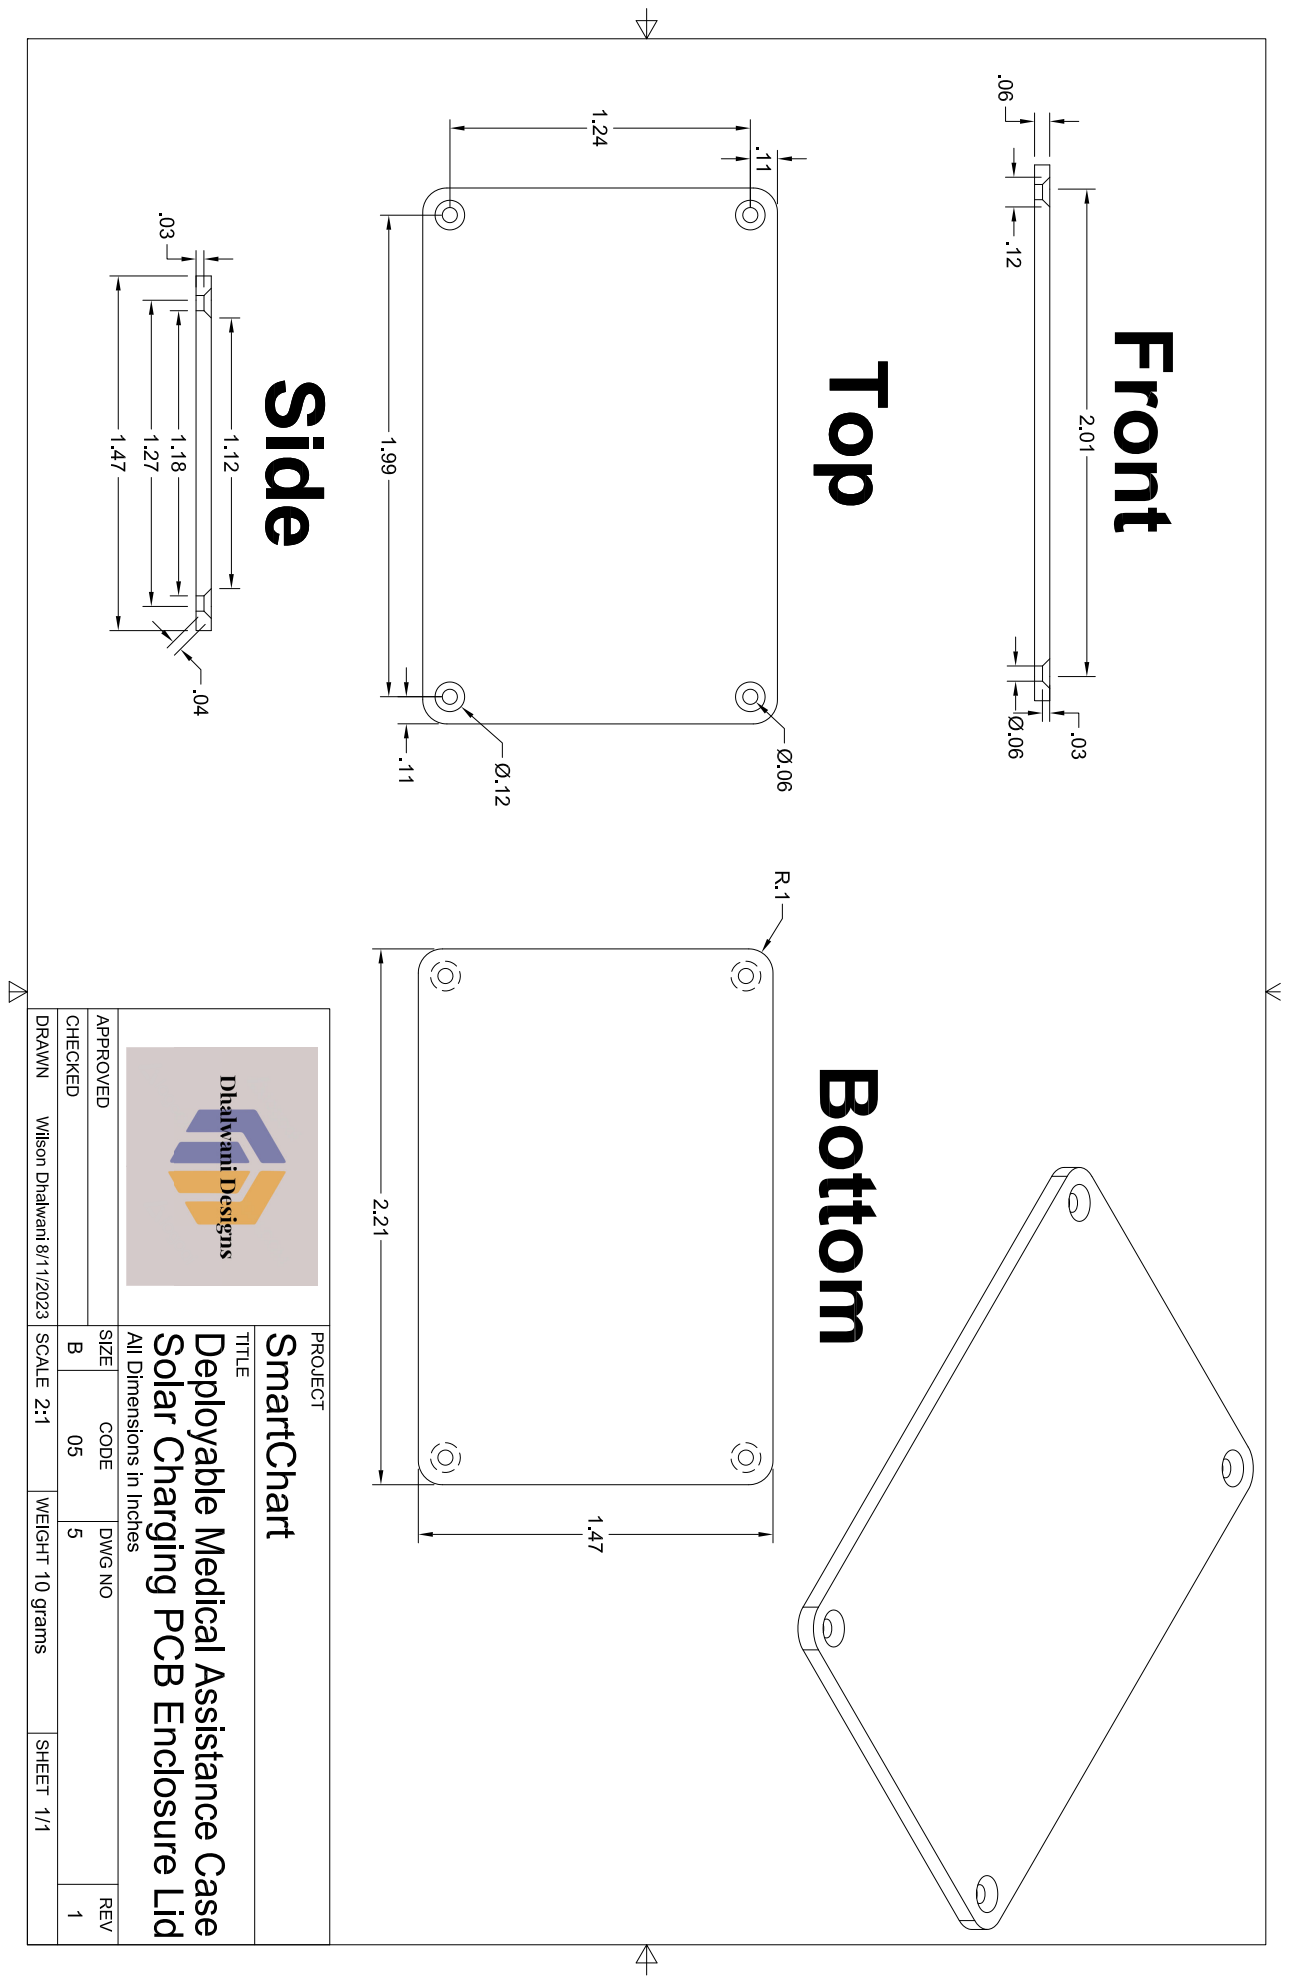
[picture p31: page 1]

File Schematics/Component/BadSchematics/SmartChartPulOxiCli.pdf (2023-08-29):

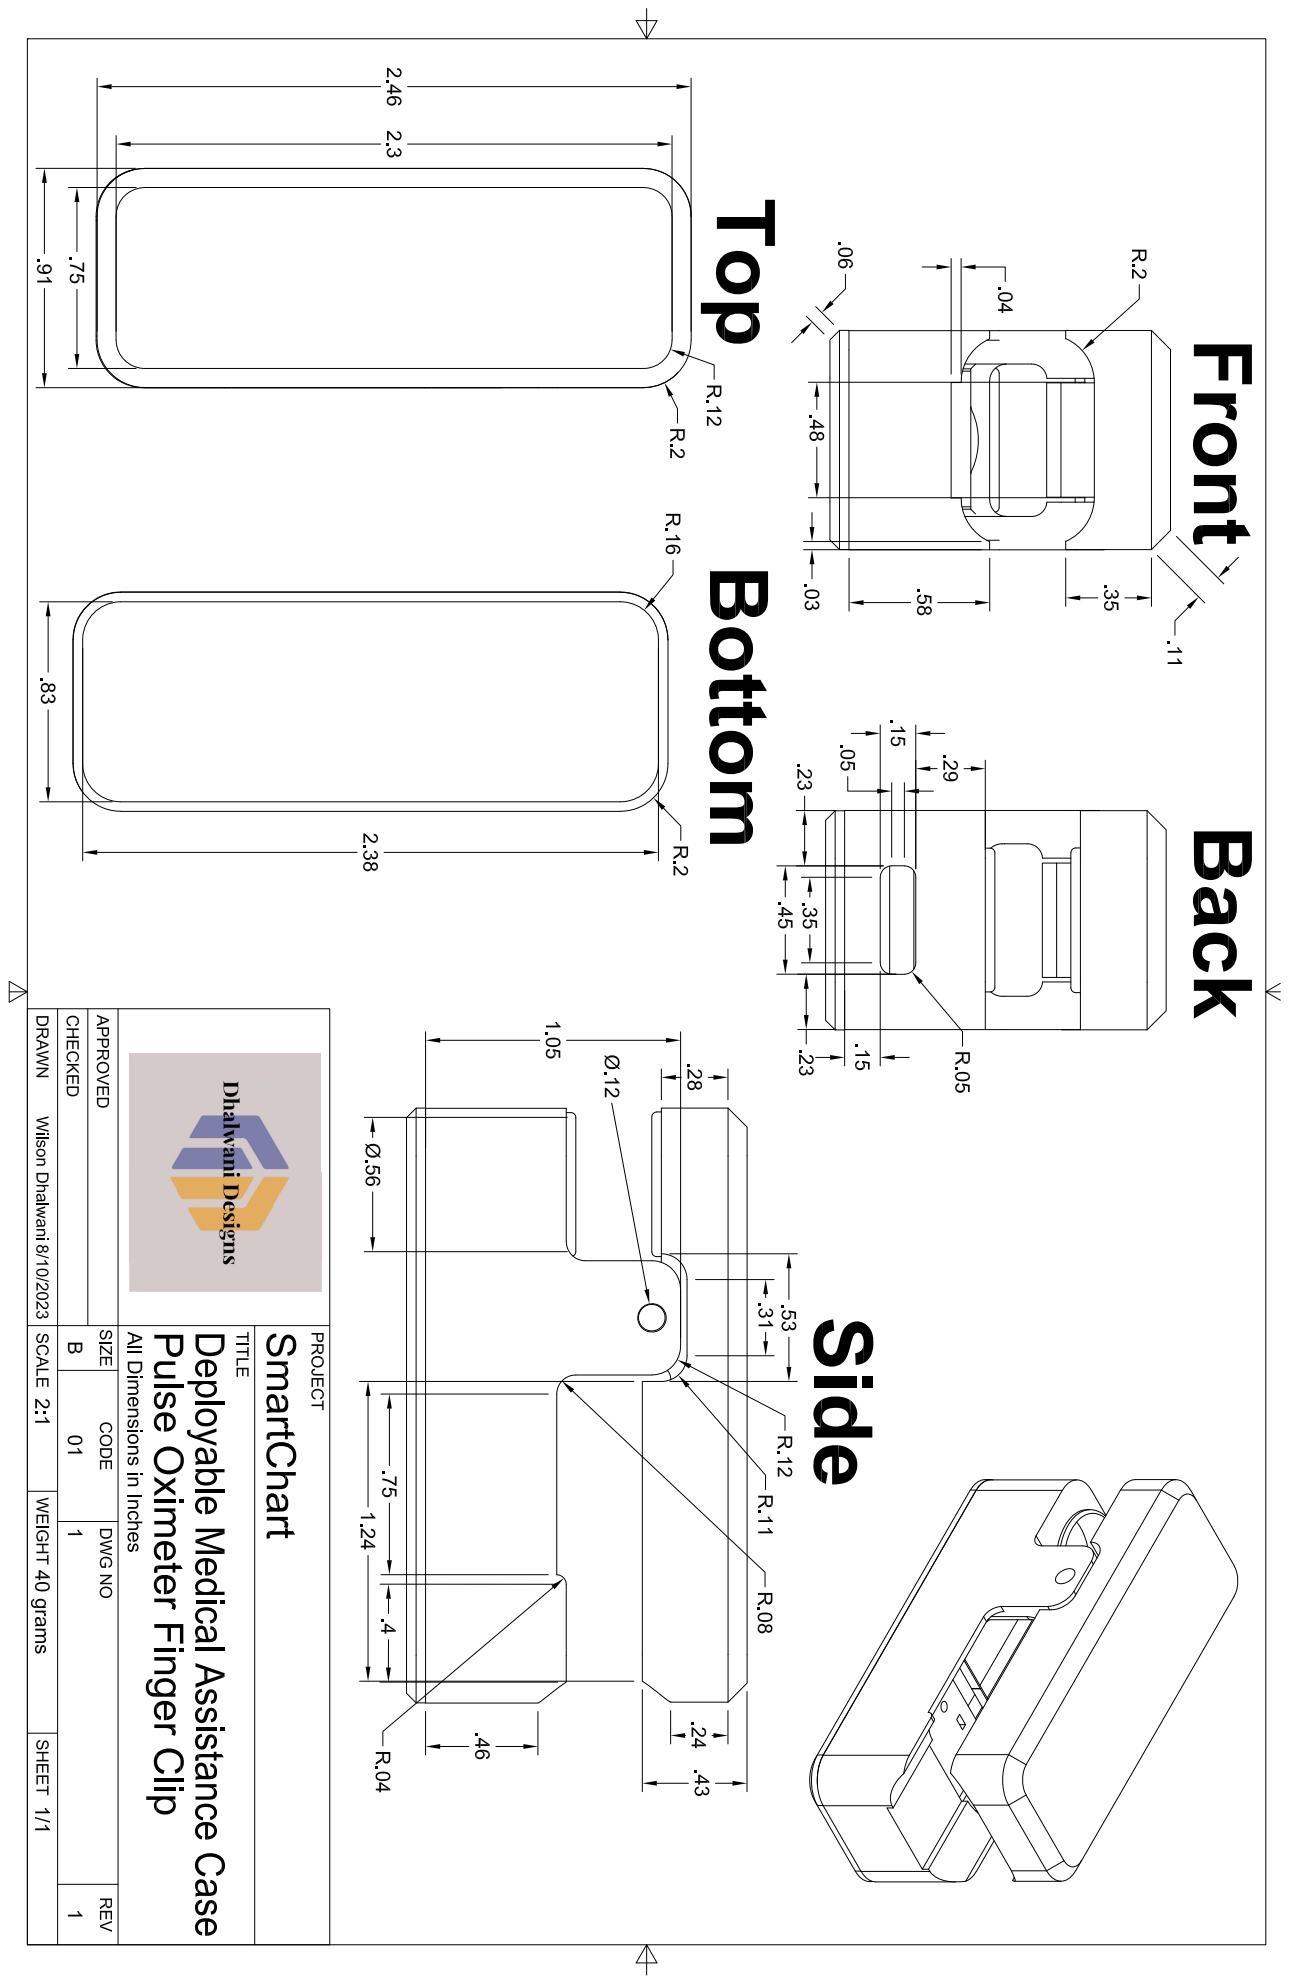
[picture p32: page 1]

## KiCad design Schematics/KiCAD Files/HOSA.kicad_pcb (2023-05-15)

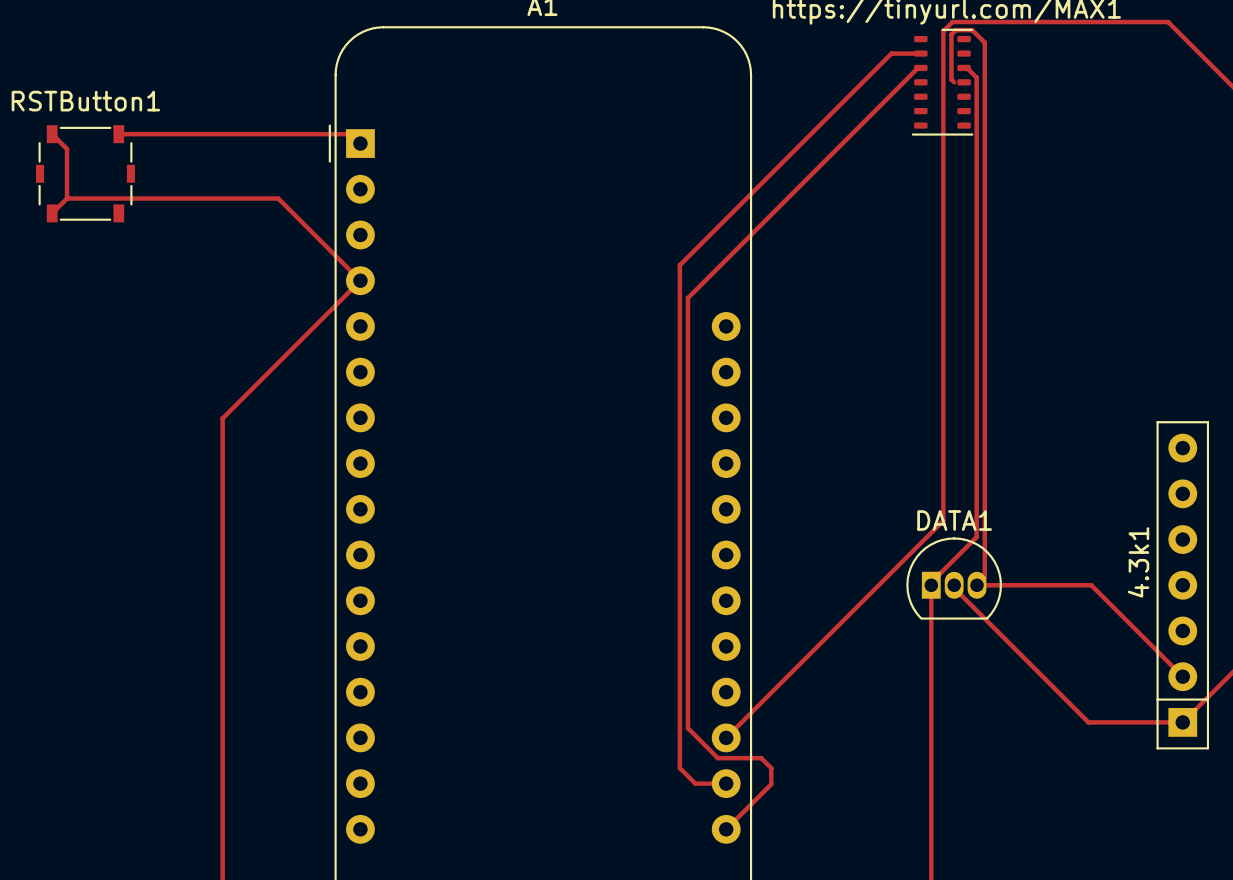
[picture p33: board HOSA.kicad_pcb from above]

Board: 2 copper layers, 5 parts (0 on the bottom side), 6 nets.

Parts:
4.3k1: 4.3kΩ; R_Array_SIP7
A1: Adafruit_Feather_HUZZAH32_ESP32_V2; Adafruit_Feather
DATA1: DS18B20; TO-92_Inline
RSTButton1: SW_Push; SW_SPST_Panasonic_EVQPL_3PL_5PL_PT_A08
https://tinyurl.com/MAX1: GY-MAX30102; Maxim_OLGA-14_3.3x5.6mm_P0.8mm

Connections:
unnamed: A1.1 (RST), RSTButton1.2
unnamed: 4.3k1.2, A1.2 (3V), DATA1.3 (VDD), https://tinyurl.com/MAX1.11 (VIN)
unnamed: A1.4 (GND), DATA1.1 (GND), RSTButton1.1, https://tinyurl.com/MAX1.12 (GND)
unnamed: A1.17 (SDA/22), https://tinyurl.com/MAX1.3 (SDA)
unnamed: A1.18 (SCL/20), https://tinyurl.com/MAX1.2 (SCL)
unnamed: 4.3k1.1, A1.19 (A6/14), DATA1.2 (DQ)

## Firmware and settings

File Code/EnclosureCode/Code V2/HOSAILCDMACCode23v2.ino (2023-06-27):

/* 
  Name: Wilson Dhalwani 
  Date: 5/9/23 
  Projekt: HOSA ILC DMAC
  Credits: 
    -> SparkFun MAX3010x Sensor Library for help with GYMAX30102 Sensor
    -> https://www.instructables.com/DS18B20-temperature-probe-with-LCD/ for help with temp sensor 
    -> https://randomnerdtutorials.com/esp32-wifimulti/#:~:text=It%20allows%20you%20to%20register,next%20network%20on%20the%20list for help with multiconnectWifi
    -> Giacomo Pugliese for help with website interfacing
    -> Myself for the rest (yes I actually had to program a lot; it was fun tho)
  Notes: 
    Hello either Future Wilson or HOSA ILC Judges!!!! :))
      -> If Future Wilson: 
          > Make sure to change the wifi for the one that is currently accesible
          > Also Battery Capacitance
            - Prob will either be 500 mAh or 2000 mAh
          > Light Table 
            - Red: Bad; Some Error (Reset board and adjust; Check serial monitor)
            - Green: GOOD GOOD GOOD YOU ARE FINALLY DOING SOMETHING GOOD 
            - Blue: We be loadin yk 
          //////////////////////////////////////////////////////////////////////////////////////////////> deviceID = 123005; CAN BE FOUND DOWN BELOW
          > deviceID = 5261; CAN BE FOUND DOWN BELOW
      -> If HOSA ILC Judges: 
          > Have a good day, and enjoy our projekt !!!! 
*/


//Libraries
#include <Arduino.h>
#include <WiFi.h>
#include <WiFiMulti.h>
#include <HTTPClient.h>
#include <SoftwareSerial.h>
#include <OneWire.h>
#include "MAX30105.h"
#include "spo2_algorithm.h"
#include "heartRate.h"

//WIFI and Website Stuff
  //HOME
  //  const char* WIFI_SSID = "wifiuser";
  //  const char* WIFI_PASS = "wifipassword";
  //SCHOOL
  //  const char* WIFI_SSID = "Bergen-Staff";
  //  const char* WIFI_PASS = "I@m@nEduc@tor";
  //GIACOMO iPhone
  //  const char* WIFI_SSID = "Giacomo-iPhone";
  //  const char* WIFI_PASS = "Octane3245";  
  //Wilson iPhone
    const char* WIFI_SSID = "Midlandswim iPhone";
    const char* WIFI_PASS = "wd123456";
  //HOSA ILC
  //  const char* WIFI_SSID = "HOSAILC23";
  //  const char* WIFI_PASS = "2023!Hosa";


//Wifi & Website
  const char* FASTAPI_BACKEND_URL = "https://smart-chart-backend-8726395027f2.herokuapp.com/data";
  HTTPClient http;

//Temp Sensor Stuff
  int DS18S20_Pin = 32;        //DS18S20 Signal pin on digital 32
  char tmpstring[10];
  OneWire ds(DS18S20_Pin);   //Temperature chip i/o

//battery Stuff
  const float VOLTAGE_DIVIDER_RATIO = 2.0;   // Voltage divider ratio
  const float VOLTAGE_DIVIDER_OFFSET = 0.0;  // Voltage divider offset
  const float BATTERY_CAPACITY = 500.0;      // Battery capacity in mAh   
  //const float BATTERY_CAPACITY = 2000.0;      // Battery capacity in mAh  FOR BIG BOI BATTERY
  const float BATTERY_VOLTAGE_MIN = 3.0;     // Minimum safe battery voltage
  //const float BATTERY_VOLTAGE_MID = 3.7;     // Minimum safe battery voltage NEVER USED, ONLY FOR REFERENCE
  const float BATTERY_VOLTAGE_MAX = 4.2;     // Maximum safe battery voltage
  float battery_voltage = 0.0;     // Battery voltage in volts
  float battery_percentage = 0.0;  // Battery life percentage

//PulseOxi Sensor Stuff
  MAX30105 particleSensor;
  #define MAX_BRIGHTNESS 255
  #if defined(__AVR_ATmega328P__) || defined(__AVR_ATmega168__)
  //Arduino Uno doesn't have enough SRAM to store 100 samples of IR led data and red led data in 32-bit format
  //To solve this problem, 16-bit MSB of the sampled data will be truncated. Samples become 16-bit data.
  uint16_t irBuffer[100];   //infrared LED sensor data
  uint16_t redBuffer[100];  //red LED sensor data
  #else
  uint32_t irBuffer[100];   //infrared LED sensor data
  uint32_t redBuffer[100];  //red LED sensor data
  #endif
  int32_t bufferLength;   //data length
  int32_t spo2;           //SPO2 value
  int8_t validSPO2;       //indicator to show if the SPO2 calculation is valid
  int32_t heartRate;      //heart rate value
  int8_t validHeartRate;  //indicator to show if the heart rate calculation is valid
  byte pulseLED = 14;  //Must be on PWM pin
  byte readLED = 13;   //Blinks with each data read

//Where the fun begins! Initilization
void setup() {  
  //board initator
    Serial.begin(115200);

  WiFi.begin(WIFI_SSID, WIFI_PASS);

  while (WiFi.status() != WL_CONNECTED) {
    delay(1000);
    Serial.println("Connecting to Wi-Fi...");
    neopixelWrite(0, 0, 0, 255);
  }

  Serial.println("Connected to Wi-Fi!");
  neopixelWrite(0, 0, 255, 0);

  // Configure ADC for 12-bit resolution and voltage range of 0-3.3V
    analogReadResolution(12);
    analogSetAttenuation(ADC_11db);
    pinMode(pulseLED, OUTPUT);
    pinMode(readLED, OUTPUT);

  // Initialize sensor
    if (!particleSensor.begin(Wire, I2C_SPEED_FAST))  //Use default I2C port, 400kHz speed
    {
      Serial.println(F("MAX30105 was not found. Please check wiring/power."));
      neopixelWrite(0, 255, 0, 0);
      while (1)
        ;
    }

  //load and implement custom settings
    neopixelWrite(0, 0, 255, 0);
    byte ledBrightness = 60;  //Options: 0=Off to 255=50mA
    byte sampleAverage = 1;   //Options: 1, 2, 4, 8, 16, 32  (1 gives way more accurate bpm)
    byte ledMode = 2;         //Options: 1 = Red only, 2 = Red + IR, 3 = Red + IR + Green
    byte sampleRate = 100;    //Options: 50, 100, 200, 400, 800, 1000, 1600, 3200
    int pulseWidth = 411;     //Options: 69, 118, 215, 411
    int adcRange = 4096;      //Options: 2048, 4096, 8192, 16384

    particleSensor.setup(ledBrightness, sampleAverage, ledMode, sampleRate, pulseWidth, adcRange);  //Configure sensor with these settings
}

//gettemp from sensor function
float getTemp() {
  //returns the temperature from one DS18S20 in DEG Celsius

  byte data[12];
  byte addr[8];

  if (!ds.search(addr)) {
    //no more sensors on chain, reset search
    ds.reset_search();
    return -1000;
  }

  if (OneWire::crc8(addr, 7) != addr[7]) {
    Serial.println("CRC is not valid!");
    neopixelWrite(0, 255, 0, 0);
    return -1000;
  }

  if (addr[0] != 0x10 && addr[0] != 0x28) {
    Serial.print("Device is not recognized");
    neopixelWrite(0, 255, 0, 0);
    return -1000;
  }

  ds.reset();
  ds.select(addr);
  ds.write(0x44, 1);  // start conversion, with parasite power on at the end

  byte present = ds.reset();
  ds.select(addr);
  ds.write(0xBE);  // Read Scratchpad

  for (int i = 0; i < 9; i++) {  // we need 9 bytes
    data[i] = ds.read();
  }

  ds.reset_search();

  byte MSB = data[1];
  byte LSB = data[0];

  float tempRead = ((MSB << 8) | LSB);  //using two's compliment
  float TemperatureSum = tempRead / 16;

  return TemperatureSum;
}

//Where the fun perpetuates into either bliss or chaos....
void loop() {

  //temp sensor
    float temperature = getTemp();
    float tmp = (int)temperature;   //in celsious
    float tempF = ((tmp * 1.8) + 32);   //1.8 = 9/5 so gives farenheit
    Serial.println(tempF);

  //batteryLife
    // Read battery voltage using voltage divider circuit
    int battery_adc_value = analogRead(35);                                                    // ADC channel 35 (GPIO35)
    float battery_adc_voltage = (battery_adc_value / 4095.0) * 3.3;                            // Convert ADC value to voltage
    battery_voltage = (battery_adc_voltage * VOLTAGE_DIVIDER_RATIO) + VOLTAGE_DIVIDER_OFFSET;  // Calculate battery voltage
    // Calculate battery life percentage
    battery_percentage = ((battery_voltage - BATTERY_VOLTAGE_MIN) / (BATTERY_VOLTAGE_MAX - BATTERY_VOLTAGE_MIN)) * 100.0;
    if (battery_percentage > 100.0) {
      battery_percentage = 100.0;
    } else if (battery_percentage < 0.0) {
      battery_percentage = 0.0;
    }
    // Print battery information to serial monitor
    Serial.print("Battery Voltage: ");
    Serial.print(battery_voltage, 2);
    Serial.print(" V, Battery Life: ");
    Serial.print(battery_percentage, 0);
    Serial.println("%");

  //MAX30102
    bufferLength = 100;  //buffer length of 100 stores 4 seconds of samples running at 25sps
    //read the first 100 samples, and determine the signal range
    for (byte i = 0; i < bufferLength; i++) {
      while (particleSensor.available() == false)  //do we have new data?
        particleSensor.check();                    //Check the sensor for new data
      redBuffer[i] = particleSensor.getRed();
      irBuffer[i] = particleSensor.getIR();
      particleSensor.nextSample();  //We're finished with this sample so move to next sample
      neopixelWrite(0, 0, 0, 255); 
      Serial.println("Calibrating..."); 
      // Serial.print(F("red="));
      // Serial.print(redBuffer[i], DEC);
      // Serial.print(F(", ir="));
      // Serial.println(irBuffer[i], DEC);
    }

    //calculate heart rate and SpO2 after first 100 samples (first 4 seconds of samples)
    maxim_heart_rate_and_oxygen_saturation(irBuffer, bufferLength, redBuffer, &spo2, &validSPO2, &heartRate, &validHeartRate);


  //Continuously taking samples from MAX30102, temp sensor, and then sends to website.  
  while (1) {
    
    //data assignments
      float temp = tempF;
      float battLife = battery_percentage;
      int deviceID = 5261;
      float HeartRate = heartRate;  //HR should be between 60 and 95 
      float Spo2 = spo2;       //SPO2 should be between 95 and 100
      float alive = 1; 
 

    //send data to Website
      if (WiFi.status() == WL_CONNECTED) {
        String json = "{\"temp\": " + String(temp) + ", \"battLife\": " + String(battLife) + ", \"deviceID\": " + String(deviceID) + ", \"HeartRate\": " + String(HeartRate) + ", \"Spo2\": " + String(Spo2) + ", \"alive\": " + String(alive) + "}";
        http.begin(FASTAPI_BACKEND_URL);
        http.addHeader("Content-Type", "application/json");
        //Serial.println("Hello");
        int httpCode = http.POST(json);
        String payload = http.getString();

        if (httpCode > 0) {
          Serial.println("Values sent to the FastAPI backend!");
          neopixelWrite(0, 0, 255, 0);
        } else {
          neopixelWrite(0, 255, 0, 0);
          Serial.print("Error sending values. HTTP code: ");
          Serial.println(httpCode);
        }

        http.end();
      } else {
        Serial.println("Error connecting to the FastAPI backend!");
        neopixelWrite(0, 255, 0, 0);
      }

    //help the memory
      //dumping the first 25 sets of samples in the memory and shift the last 75 sets of samples to the top
      for (byte i = 25; i < 100; i++) {
        redBuffer[i - 25] = redBuffer[i];
        irBuffer[i - 25] = irBuffer[i];
      }

    //keep taking data, end if no finger
      //take 25 sets of samples before calculating the heart rate.
      for (byte i = 75; i < 100; i++) {
        while (particleSensor.available() == false)  //do we have new data?
          particleSensor.check();                    //Check the sensor for new data

        digitalWrite(readLED, !digitalRead(readLED));  //Blink onboard LED with every data read

        redBuffer[i] = particleSensor.getRed();
        irBuffer[i] = particleSensor.getIR();
        particleSensor.nextSample();  //We're finished with this sample so move to next sample

        if (irBuffer[i] < 6000) {
          Serial.println(F("No Finger in Clip! Reset Board."));
          neopixelWrite(0, 255, 0, 0);
          while (1);
        }

      //display that info to Serial monitor
        //send samples and calculation result to terminal program through UART
        Serial.print(F("red="));
        Serial.print(redBuffer[i], DEC);
        Serial.print(F(", ir="));
        Serial.print(irBuffer[i], DEC);

        Serial.print(F(", HR="));
        Serial.print(heartRate, DEC);

        Serial.print(F(", HRvalid="));
        Serial.print(validHeartRate, DEC);

        Serial.print(F(", Temp="));
        Serial.print(tempF, DEC);

        Serial.print(F(", BattLife="));
        Serial.print(battery_percentage, DEC);

        Serial.print(F(", SPO2="));
        Serial.print(spo2, DEC);

        Serial.print(F(", SPO2Valid="));
        Serial.println(validSPO2, DEC);
    }

    //MAX30102
      //After gathering 25 new samples recalculate HR and SP02
      maxim_heart_rate_and_oxygen_saturation(irBuffer, bufferLength, redBuffer, &spo2, &validSPO2, &heartRate, &validHeartRate);

    //tempSensor
      float temperature = getTemp();
      float tmp = (int)temperature;
      float tempF = ((tmp * 1.8) + 32);

    //batteryLife
      // Read battery voltage using voltage divider circuit
      int battery_adc_value = analogRead(35);                                                    // ADC channel 35 (GPIO35)
      float battery_adc_voltage = (battery_adc_value / 4095.0) * 3.3;                            // Convert ADC value to voltage
      battery_voltage = (battery_adc_voltage * VOLTAGE_DIVIDER_RATIO) + VOLTAGE_DIVIDER_OFFSET;  // Calculate battery voltage
      // Calculate battery life percentage
      battery_percentage = ((battery_voltage - BATTERY_VOLTAGE_MIN) / (BATTERY_VOLTAGE_MAX - BATTERY_VOLTAGE_MIN)) * 100.0;
      if (battery_percentage > 100.0) {
      battery_percentage = 100.0;
      } else if (battery_percentage < 0.0) {
        battery_percentage = 0.0;
      }

    delay(1000);
  }
}

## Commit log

2023-05-15 SmartChart Website and AI Code
    Created and programmed by Giacomo Pugliese, downloaded and attached here for reference.
2023-05-15 Screw CAD for Solar Charger Enclosure
    Not Made by myself, borrowed from online, no credit to me for these.
    [92010A781_Passivated 18-8 Stainless Steel Phillips Flat Head Screw .f3d, 92010A781_Passivated 18-8 Stainless Steel Phillips Flat Head Screw STEP.step, 92010A78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]
2023-05-15 Custom CAD Solar Charger Board
    Made by me
    [MCP73871 Solar Charger Controller STEP.step, MCP73871 Solar Charger Controller STL.stl, MCP73871 Solar Charger Controller.f3d]
2023-05-15 Custom CAD GY-MAX30102 Board
    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
    [GY-MAX30102 Component CAD.f3d, GY-MAX30102 Component STEP.step, GY-MAX30102 Component STL.stl]
2023-05-15 Custom CAD Enclosure Wall Designs
    These were made by me. They are installed in a separate custom enclosure.
    [HOSAEnclosureWalls .step, HOSAEnclosureWalls DoubleHole STL.stl, HOSAEnclosureWalls STEP.step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]
2023-05-15 Custom CAD Pulse Oximeter Clip
    Made by me. Inspired by https://www.thingiverse.com/thing:4847827
    [PulseOximeterClip Bottom STL.stl, PulseOximeterClip STEP.step, PulseOximeterClip.f3z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]
2023-05-15 Custom CAD MCP73871 Enclosure
    Made by me. The exception is the screws used. The Accyrlic Cover is not meant to be printed, but rather for reference.
    [MCP73871Enclosure .f3z, MCP73871Enclosure Accrylic Cover STL.stl, MCP73871Enclosure Body STL.stl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]
2023-06-13 Internal Electronics for DMAC Processing Enclosure
    Sorry guys, it's messy, really messy (I know). The ultimate shame of any electrical engineering student.... but hey- we have pretty enclosures for a reason! To hide the shame, we hope no one will eve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
2023-08-29 Engineering Schematics
    These were also submitted for Patent
2023-08-29 Bad Schematic
    Put it here for fun. Not for any reference or actual use.
2023-08-29 KiCad Schematics
    Newer Version. Made some improvements
2023-08-29 PCB Iteration 1
    The first PCB Design
2023-08-29 First PCB Design
    Iteration 1, done in KiCAD
